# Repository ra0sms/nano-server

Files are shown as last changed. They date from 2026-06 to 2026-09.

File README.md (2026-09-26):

# Nano Server — Remote Radio Station Server

**Nano Server** is a server-side component of a remote ham radio station system. It runs on a **NanoPi NEO** single-board computer with **Armbian** and provides audio streaming, PTT control via GPIO, video streaming, relay switching, CAT interface forwarding, CW keying, and a web-based configuration interface.

Desktop client software: https://github.com/ra0sms/caesar-client-desktop

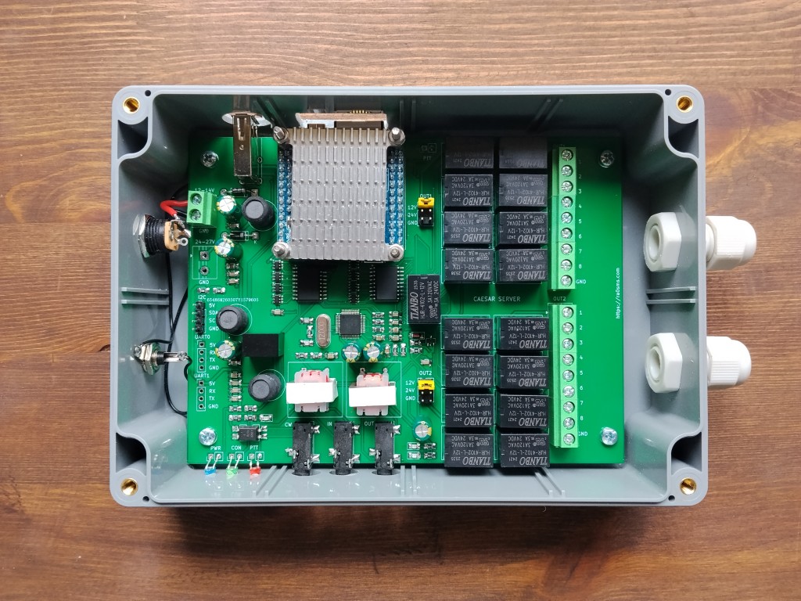
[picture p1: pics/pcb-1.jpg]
PCB


---

## Features

- 🎙️ **Bidirectional audio** over UDP (GStreamer + Opus codec)
- 📡 **PTT control** via GPIO with client reachability monitoring
- 📷 **Video streaming** via mjpg-streamer (MJPEG over HTTP)
- 🔌 **Relay control** via I2C (2×PCF8574T, 16 relays total)
- 🌐 **Web interface** — relays, TRX, band relay rules, audio, config, settings, self-update (single UI on port 5050)
- 🔗 **CAT interface** forwarding over TCP (Icom CI-V and Kenwood protocols)
- 🔄 **UART1 transparent relay** — CAT data duplicated to physical UART1 port for local computer access
- 🔒 **Fail-safe** — PTT is forced OFF when client disconnects; a CW message in progress is stopped and the CW key line released too (with break-in the radio would otherwise keep transmitting on the key alone)
- 🚫 **PTT Lock** — relay switching (manual and band relay) is blocked while PTT is active to prevent accidental antenna switching during transmission
- 🎛️ **Band Relay Rules** — automatic relay switching based on transceiver frequency
- 🔑 **CW Keyer** — Winkeyer protocol over UDP, generates Morse code on GPIO PC1
- 🔄 **Self-update** — checks GitHub for a newer release tag, shows its changelog, and applies it (`git pull` + restart of all related systemd services) from the web UI

---

## Hardware

| Component | Details |
|---|---|
| SBC | NanoPi NEO (Allwinner H3) |
| OS | Armbian (Debian Bookworm or later) |
| Audio | USB sound card (C-Media USB Audio Device) |
| Camera | USB webcam on `/dev/video1` |
| Relay board | 2× I2C GPIO expander at `0x20` / `0x21` |
| CAT interface | USB-to-Serial (port chosen in web Settings tab, e.g. `/dev/ttyUSB0`) |
| CAT UART1 relay | Physical UART1 on `/dev/ttyS1` (pins 8-TX, 10-RX) |
| CON LED | GPIO PC2 (line 66) |
| PTT output | GPIO PC3 (line 67) |
| CW Keyer output | GPIO PC1 (line 65) |

---

## Architecture

```
Client PC                          NanoPi NEO (Server)
─────────────────────────────────────────────────────────
                    UDP :5000  ←──  Audio TX (mic → client)
                    UDP :5000  ──→  Audio RX (client → speaker)
                    UDP :5001  ──→  PTT commands (0/1)
                    UDP :5002  ←→   Ping / RTT monitoring
                    UDP :5003  ──→  CW Keyer (Winkeyer protocol, UDP)
                    TCP :5050  ←──  Web UI (Flask): relays, TRX, band relay, audio, config, settings, update (live status over SSE)
                    TCP :6789  ←──  CW XML-RPC (PyWinKeyerSerial / not1mm)
                    TCP :8081  ←──  MJPEG video stream
                    TCP :3001  ←──  CAT (Icom CI-V or Kenwood)

Local PC (UART1)                   NanoPi NEO (Server)
─────────────────────────────────────────────────────────
                    UART1 (ttyS1) ←→  Transparent CAT relay (bidirectional)
```

### Systemd services

| Service | Description |
|---|---|
| `ptt_server` | PTT + CW Keyer + client monitor + ping responder (single service, all GPIO) |
| `audio_server` | GStreamer audio TX (server mic → client) |
| `audio_client_on_server` | GStreamer audio RX (client → server speaker) |
| `relay-web` | Web UI: relays, TRX, band relay, audio, config, settings, update (port 5050) |
| `mjpeg-streamer` | MJPEG video stream from USB camera |
| `alsa_restore` | Restores ALSA mixer state at boot |

---

## Installation

### 1. Flash Armbian to SD card and boot NanoPi NEO

### 2. Clone the repository

```bash
git clone https://github.com/ra0sms/nano-server.git
cd /home/pi/nano-server
```

### 3. Run the install script as root

```bash
sudo bash install_server.sh
```

The script will:
- Install all required packages (GStreamer, Flask, gpiod, mjpg-streamer, etc.)
- Build and install **mjpg-streamer** from source
- Create `client_ip.cfg`, `server_ip.cfg`, and `web/password.txt` with defaults
- Configure hardware overlays in `/boot/armbianEnv.txt`
- Register and start all systemd services
- Add sudoers entries for `restart_services_on_server.sh`, `systemctl restart/stop/start relay-web`, and `alsactl store` (so Audio tab volume changes persist across reboot)

### 4. Set IP addresses

```bash
echo '192.168.1.100' > /home/pi/nano-server/client_ip.cfg   # IP of the client PC
echo '192.168.1.10'  > /home/pi/nano-server/server_ip.cfg   # IP of this server
```

Or use the web interface at `http://<server-ip>:5050/`.

### 5. Change the default password for the web panel

```bash
echo 'yourpassword' > /home/pi/nano-server/web/password.txt
```

### 6. (Optional) Fix ALSA card order

If you have multiple USB audio devices (e.g., webcam with mic), the C-Media USB Audio card may not be card 0. Run:

```bash
sudo bash /home/pi/nano-server/fix_alsa_card_order.sh
sudo reboot
```

### 7. Reboot

```bash
sudo reboot
```

---

## Armbian Hardware Configuration

The script `setup_armbian_env.sh` patches `/boot/armbianEnv.txt` to enable the required device tree overlays. It **never modifies** `rootdev` or `rootfstype` so the system remains bootable.

To apply manually on a running system:

```bash
sudo bash /home/pi/nano-server/setup_armbian_env.sh
sudo reboot
```

Required overlays: `i2c0 uart1 uart2 uart3 usbhost0 usbhost1 usbhost2 usbhost3 w1-gpio`

---

## Web Interface — port 5050

Access at `http://<ip>:5050/` (password protected).
Default password: `1234` — change it in `web/password.txt`.

| Tab | Description |
|---|---|
| Main | Relay switching (16 relays, toggle/switch modes) and camera view |
| TRX | Transceiver frequency, band, mode display, and **Band Relay** frequency-based automatic relay switching rules |
| Audio | Speaker and mic level control via ALSA, audio stream settings (sample rate/buffer), restart audio services |
| Config | IP addresses, saved profiles, network status (client RTT / connection status, local IP) |
| Settings | Relay names, group modes, TRX serial port and protocol, UART1 transparent relay toggle |
| Update | Check GitHub for a newer release, view its changelog, apply the update and restart the web panel |

### Persistent Status Bar & Real-Time Updates

A **status bar** is shown at the top of every tab with the current PTT state, the transceiver online/frequency indicator, and the client link latency (RTT):

- **PTT** — turns red (`● PTT: ON`) while transmitting, grey otherwise.
- **TRX** — `🟢 ONLINE` / `🔴 OFFLINE` plus the live frequency.
- **Client** — round-trip time to the client PC in milliseconds.

Live values are pushed to the browser over **Server-Sent Events** (SSE, `GET /events`). The server sends a combined snapshot (PTT, relay state, TRX frequency/band/mode, client RTT, band-relay current state) that is emitted only when it changes, replacing the previous per-tab HTTP polling every 2 s. This makes status changes appear immediately and reduces load on the device. The SSE stream requires an authenticated session (cookies are sent automatically by the browser) and reconnects automatically if dropped.

### Band Relay Rules

Configure which relays activate for each frequency range (in kHz). Rules use `from ≤ freq < to` logic (lower bound inclusive, upper bound exclusive). To avoid gaps, set `to` of one rule equal to `from` of the next.

Example:
- `1800-1840` kHz → relays 1, 2
- `1840-1900` kHz → relays 3, 4
- `7000-7300` kHz → relays 5, 6

Auto-switching can be toggled on/off via a checkbox in the TRX tab. Rules are validated on the server (numeric `from < to` in kHz, relay numbers 1–16); if `web/band_rules.json` is unreadable at startup, it is renamed to `band_rules.json.invalid` and the default rules are used.

**Group-scoped auto-switching:** auto-switching only touches the relay group(s) that the configured rules actually reference, leaving the other group fully manual:

- If the saved rules only use relays **1–8**, then relays **9–16** are never reset or switched automatically — they can be selected manually and their state is preserved across every frequency change (and vice versa).
- If the rules reference relays from both groups, both are auto-managed (all selected relays are reset and re-applied as before).
- If no rule references any relay, auto-switching leaves all 16 relays untouched.

This makes it possible to dedicate one relay group to automatic antenna/band switching while keeping the other group for manually-controlled devices.

**Switching only on a band change, with confirmation:** relays are switched only when the frequency moves into a range with a *different* relay set, and only after two frequency readings at least 0.3 s apart agree. This means:

- a single corrupted CAT frame can't flip the antenna;
- tuning back and forth across a range boundary doesn't chatter the relays;
- a relay toggled by hand inside an auto-managed group stays as set until the next band change (it is no longer reset on every CAT reading).

While a band change waits for its confirming reading, the server polls the transceiver right away (subject to the external-program collision guard), so the switch still happens promptly. Saving the rules or re-enabling auto-switching re-applies them on the next reading.

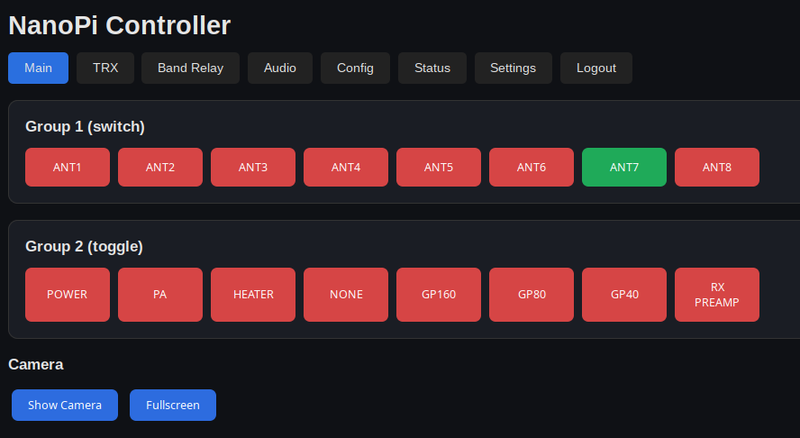
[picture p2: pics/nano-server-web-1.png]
WEB1


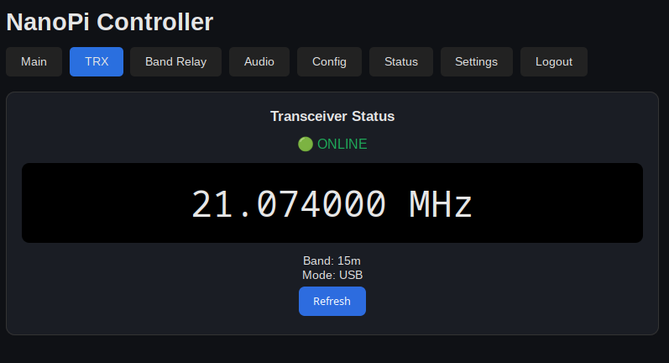
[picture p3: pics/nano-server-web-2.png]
WEB2


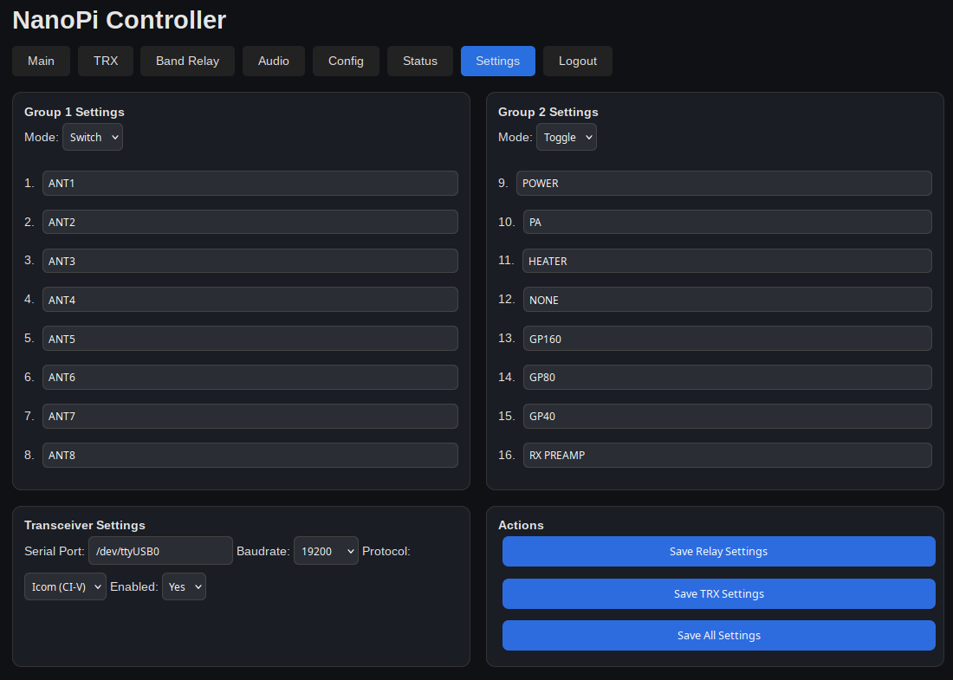
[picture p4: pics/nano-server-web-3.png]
WEB3


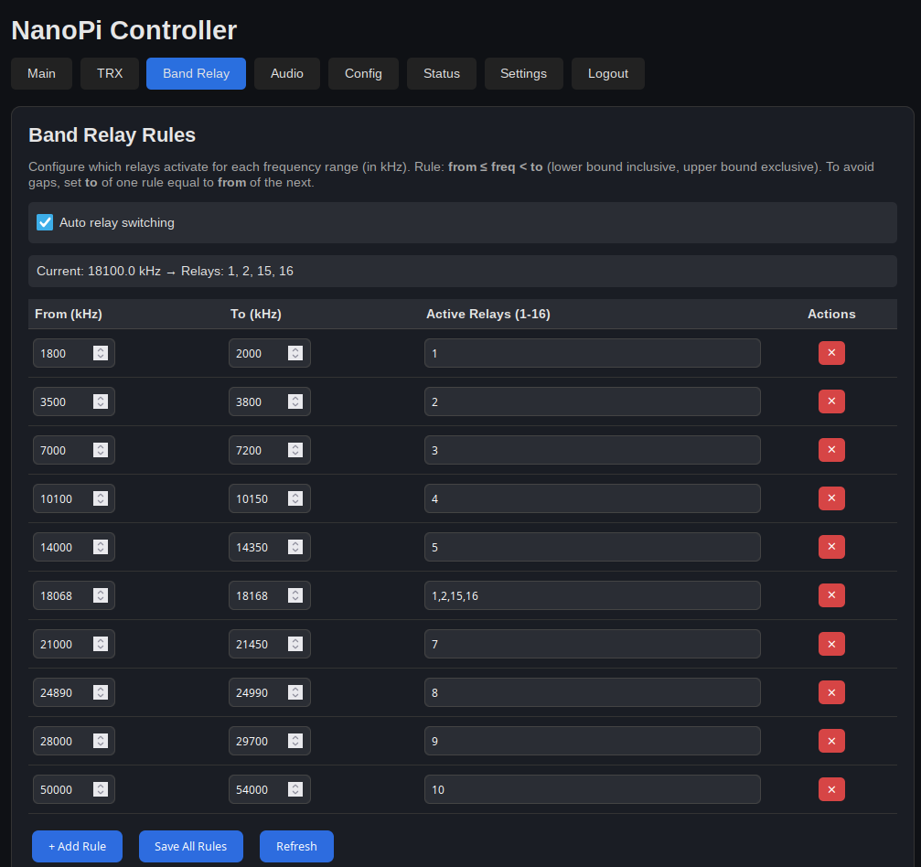
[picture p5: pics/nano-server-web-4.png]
WEB4


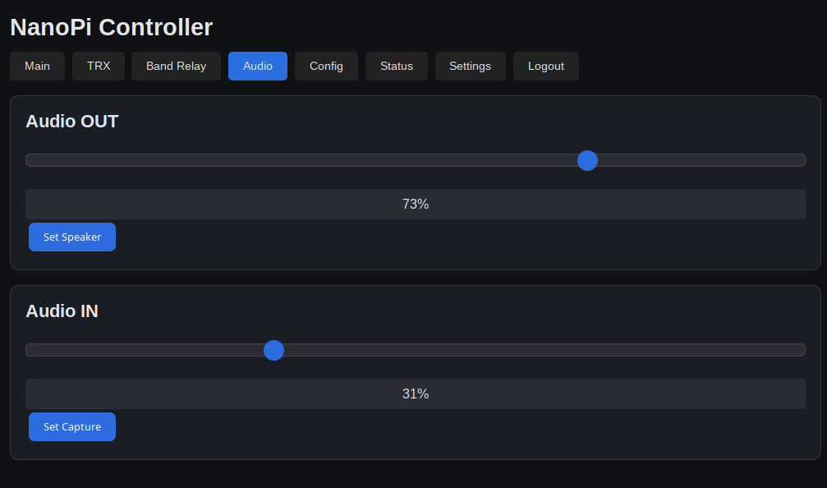
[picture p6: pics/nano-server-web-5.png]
WEB5


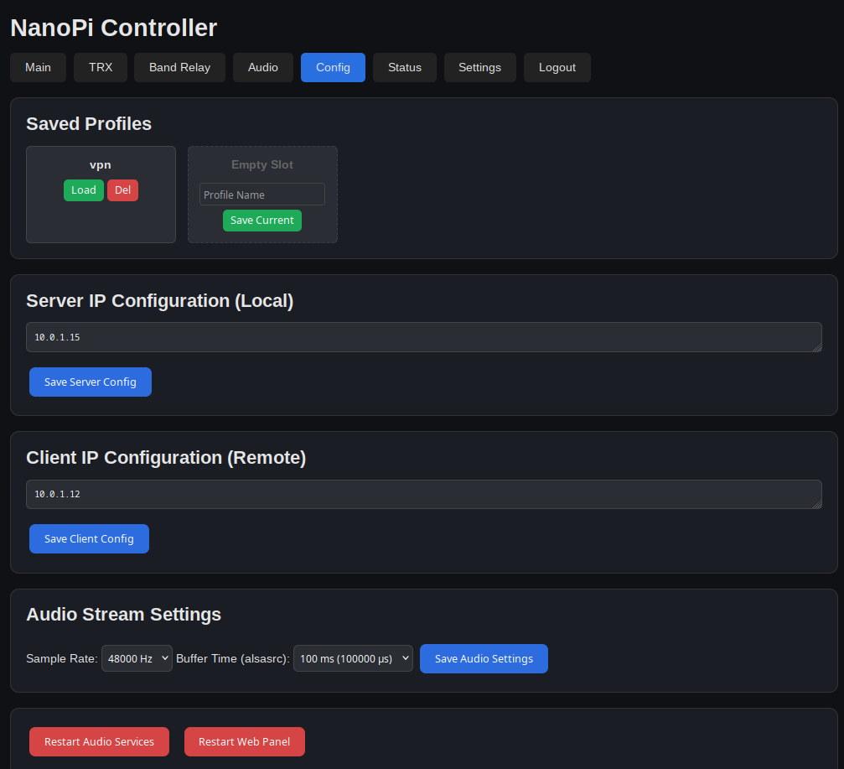
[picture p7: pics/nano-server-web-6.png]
WEB6


### PTT Lock — Relay Protection During Transmission

When PTT is active (transmitting), all relay switching is automatically blocked to prevent accidental antenna switching during transmission. This protects both the transceiver and the antenna system.

**How it works:**
1. [`combined_ptt_service.py`](network/combined_ptt_service.py) broadcasts the GPIO PTT status via UDP on `127.0.0.1:5004` on every change **and as a heartbeat every ~0.3 s**
2. [`web/app.py`](web/app.py) listens for these broadcasts in a background thread. If no status has arrived for 1.5 s (the web panel just restarted, or `ptt_server` is stopped/crashed), the PTT state is treated as **unknown and relays stay locked**
3. **CAT PTT** is tracked too, since programs like JTDX/WSJT-X/flrig often key the radio over CAT instead of the GPIO line:
   - TX/RX commands external programs send through the TCP port or UART1 relay (Kenwood `TX…;` / `RX…;`, Icom CI-V `1C 00 01` / `1C 00 00`)
   - the radio's own reports: TX/RX flag in the Kenwood `IF` reply and `TX…;`/`RX…;` auto-information, the Icom reply to `1C 00` (the server polls it on alternate poll cycles)
   - if the transceiver stops answering CAT for 5 s, the CAT TX state is cleared
4. Both manual relay toggle and automatic band relay switching are blocked while GPIO PTT is on, CAT PTT is on, or the PTT state is unknown
5. The web interface visually disables relay buttons (dimmed, `not-allowed` cursor). The status bar shows `PTT: ON`, `PTT: ON (CAT)`, or an orange `PTT: NO STATUS` when `ptt_server` isn't reporting

**Blocked operations:**
- Manual relay toggle via web UI buttons
- Automatic band relay switching when transceiver frequency changes
- Direct API calls to `POST /toggle/<n>` (server-side check)
- **Retuning from the web UI** — frequency step, band buttons and `/trx/set_freq`: band relays can't follow during TX, so a band change would leave the transmitter keyed into the previous band's antenna (the request is refused with HTTP 409 and a message in the UI). Frequency steps are also refused while the transceiver is offline, instead of stepping from a made-up frequency

---

### UART1 Transparent CAT Relay

The server can transparently relay all CAT data between the transceiver (connected via the USB-to-Serial CAT port selected in web Settings) and a local computer connected to the **UART1** physical port (`/dev/ttyS1`, pins 8-TX, 10-RX on NanoPi NEO). This allows two clients to share the same CAT connection simultaneously:

- **Remote client** — connects via TCP port 3001 over the network. Only `127.0.0.1`, the client IP from `client_ip.cfg`, and the IPs listed in `tcp_allowed_ips` in `web/trx_config.json` (edit the file, then restart `relay-web`; e.g. `"tcp_allowed_ips": ["192.168.1.50"]`) may connect; other connections are closed immediately, since this port can key and retune the transmitter
- **Local computer** — connected directly via UART1 (e.g., a PC next to the server)

**How it works:**

1. All data received from the transceiver on the CAT port is duplicated to both TCP clients and UART1
2. All data received from UART1 is written back to the CAT port (and thus forwarded to the transceiver)
3. All data received from TCP clients is written to the CAT port (existing behavior)

**Configuration** (in [`web/trx_config.json`](web/trx_config.json) or via web UI Settings tab):

```json
{
    "uart1_enabled": true,
    "uart1_port": "/dev/ttyS1"
}
```

The UART1 baudrate is automatically set to match the CAT port baudrate.

**Replies to the server's own requests are not forwarded.** The server's own polls (and the web UI's TRX commands) would otherwise produce replies that external programs take as answers to their own requests, causing "unexpected reply" errors and retries in Hamlib/JTDX/flrig:

- **Icom CI-V:** the server talks to the radio from its own controller address, **Server CI-V Address** in Settings (`server_addr`, default `0xE1`), not the `0xE0` that flrig/JTDX/Hamlib use (`ctrl_addr`). The radio replies to the sender's address, so frames to or from `server_addr` (including the echo on a single-wire CI-V bus) are decoded for the web UI but not passed to TCP clients or UART1. If some radio only works with `0xE0`, set Server CI-V Address to `0xE0`: everything is then forwarded, as in older versions.
- **Kenwood:** there are no addresses, so after each `IF;` poll the next `IF…;` reply (within 0.5 s) is kept back from external programs. If UART1 is unavailable (e.g., overlay not enabled), the server logs a warning and continues without it.

**Web UI toggle:** The **Settings → Transceiver Settings** tab now includes a **"UART1 transparent relay"** checkbox. It can be turned on/off directly from the web interface and takes effect immediately (the relay is re-initialized without restarting the service).

**Poller behavior with the relay enabled:**

When the UART1 transparent relay is enabled, the CAT bus can be owned by an external program on the PC (e.g. **flrig**, **TR4W**, **Hamlib**). While the external program is **actively** exchanging data, the server's internal poller backs off so its queries do not interleave with the PC's requests on the same line and corrupt the response stream.

However, the server now **automatically resumes its own polling whenever the external program is silent or absent**:

- **Relay ON + external program active** → the server's poller stays quiet; the PC program reads the transceiver directly, and the web **TRX tab** stays updated passively by decoding the responses that flow through the bridge.
- **Relay ON + external program silent/absent** → the server only skips its own poll while an external controller (via UART1 or a TCP client) has sent something within the last 0.3 s, or while the radio has answered within the last 2 s (someone is already keeping the frequency fresh). Otherwise it polls the transceiver itself, so the web **TRX tab** still shows the live frequency/mode even when no PC program is running. As soon as the external program sends traffic again, the poller hands the port back within one poll cycle.
- **Relay OFF** → internal poller enabled; the web interface queries the transceiver itself and updates the TRX tab even when no PC program is connected.

This behavior applies to **both** CAT protocols (Icom CI-V and Kenwood).

"Recently" means the radio has reported the **active** frequency in the last 2 s; other CAT traffic doesn't count (e.g. Hamlib reading only the inactive VFO).

**What the web panel decodes:**

- **Icom CI-V:** frequency and mode replies (`03`/`04`) and the radio's own **transceive** reports (`00`/`01`). With *CI-V Transceive* enabled in the radio's menu, frequency changes arrive as soon as the dial moves, so band relays react without waiting for a poll. Modes: LSB, USB, AM, CW, CW-R, RTTY, RTTY-R, FM, WFM, DV, DD. 6-byte frequencies (10 GHz+ bands, IC-905) are supported.
- **Kenwood:** `IF` (frequency, mode, TX/RX and **active VFO**), `FA`/`FB`, `MD`, `FR`. `FA`/`FB` only update the displayed frequency and band relays when they are for the VFO the radio is operating on (learned from `IF`, `FR` reports and `FR` commands external programs send). Otherwise, working on VFO B would switch antennas by VFO A's frequency. Frequency changes from the web UI are sent to the active VFO (`FB` when on VFO B).

**Stability & auto-recovery:**

All writes to the CAT port are serialized through a single thread lock (`ser_lock`), and data from each external source (every TCP client and UART1) is first split into **whole CAT frames** (terminated by `;` for Kenwood, `0xFD` for CI-V) — only complete frames are written. So a command that arrives in pieces (e.g. `F` in one TCP segment and `A;` in the next) can never have the poller's or another client's frame inserted into its middle. An unterminated tail is passed through as-is after 0.5 s. The CAT port and UART1 are read without a fixed 100 ms wait, so replies reach JTDX/flrig and UART1 immediately. Additionally, if the CAT serial port raises a read error (e.g. a temporary USB hiccup or the transceiver is powered off), the server now **automatically closes and reopens the serial ports** with retries instead of silently stalling — so a remote `JTDX`, `flrig`, or `WSJT-X` session no longer needs a full service restart to recover. Manually re-initializing from the web UI (Reconnect button / `POST /trx/reinit`) and re-initializing after a config change are also guarded by the same lock.

**Prerequisite:** UART1 overlay must be enabled in `/boot/armbianEnv.txt`:
```
overlays=i2c0 uart1 uart2 uart3 usbhost0 usbhost1 usbhost2 usbhost3 w1-gpio
```

---

## Profiles

Up to 5 configuration profiles (server IP, client IP, audio settings) can be saved and loaded from the web configuration interface. Profile files are stored in `profiles/`.

---

## Restarting Services

To restart all runtime services at once:

```bash
sudo /home/pi/nano-server/restart_services_on_server.sh
```

Or restart individual services:

```bash
sudo systemctl restart ptt_server.service
sudo systemctl restart audio_server.service
```

To restart the web panel from the UI, use the **"Restart Web Panel"** button on the Update tab (requires sudoers NOPASSWD for `systemctl restart relay-web`). The **"Restart Audio Services"** button on the Audio tab restarts `audio_server`, `audio_client_on_server`, `mjpeg-streamer`, and `ptt_server` (via `restart_services_on_server.sh`).

To reload `client_ip.cfg` without restarting the PTT service:

```bash
sudo systemctl kill -s SIGHUP ptt_server.service
```

---

## Software Update

The **Update** tab checks GitHub for a newer release and applies it without needing SSH access to the server.

- **Check for Update** fetches tags from `origin` and compares the highest `vX.Y.Z` tag to the version reachable from the currently checked-out commit (`git describe --tags`). If a newer one exists, it shows every `CHANGELOG.txt` section newer than the current version (not just the latest one), read directly from the fetched tag so it's visible even before pulling.
- **Update** runs `git pull --ff-only`, then restarts `audio_server`, `audio_client_on_server`, `mjpeg-streamer`, and `ptt_server` (via `restart_services_on_server.sh`), and finally restarts `relay-web` itself.
- Before pulling, it refuses if the checkout has local changes to any **tracked** file, or **any untracked file at all**, outside of the app's own runtime-state files (`web/config.json`, `audio/audio_config.cfg`, `web/trx_config.json`, `web/band_rules.json` — these are gitignored and rewritten by the app itself, so their local content is preserved across the pull automatically). A stray file left in the checkout (e.g. a manual backup) will block the update until it's removed or committed elsewhere.

Cutting a new release: add a `## vX.Y.Z (date)` section with a bullet list to the top of `CHANGELOG.txt`, commit, then tag and push:

```bash
git tag vX.Y.Z
git push origin main
git push origin vX.Y.Z
```

---

## Audio Configuration

Edit `audio/audio_config.cfg`:

```ini
RATE=48000       # sample rate: 48000 or 24000 Hz
LATENCY=100000   # buffer time in microseconds (100 ms)
```

Or use the **Audio Stream Settings** section on the **Audio** page in the web UI.

The web panel auto-detects the ALSA card (looks for C-Media USB Audio in `/proc/asound/cards`) and the speaker control name. Mic capture is hardcoded to `numid=8` (`Mic Capture Volume`).

---

## CW Keyer (Winkeyer Protocol)

The CW Keyer is integrated into the **`ptt_server`** service (single process, single GPIO request). It implements the **K1EL Winkeyer protocol** over UDP, generating Morse code (CW) on **GPIO PC1** (line 65).

All GPIO lines (CW=PC1, CON=PC2, PTT=PC3) are requested in a single `gpiod.request_lines()` call to avoid conflicts between separate processes on the same gpiochip.

### How it works

1. The client sends Winkeyer protocol commands via UDP to port **5003**
2. The server buffers ASCII characters and sends them as CW on GPIO PC1
3. The output pin (PC1) drives a transistor/keying circuit connected to the transceiver

### Supported commands

| Byte | Command | Description |
|---|---|---|
| `0x00` + WPM | Set speed | WPM value (5-99) |
| `0x02` | Start sending | Begin transmitting buffer |
| `0x03` | Clear buffer | Reset and stop |
| `0x0A` (LF) | Start sending | Same as 0x02 |
| `0x1B` | Immediate stop | Abort transmission |
| `0x1F` | Request status | Reply: 0x00 (idle) or 0x01 (busy) |
| `0x20`-`0x7E` | ASCII chars | Add to send buffer |
| `0x7F` | Backspace | Remove last char from buffer |

### Usage

```bash
# Send "CQ CQ DE RA0SMS" at 25 WPM
echo -ne '\x00\x19CQ CQ DE RA0SMS\x0a' | nc -u <server-ip> 5003
```

### XML-RPC interface (PyWinKeyerSerial / not1mm compatible)

The service provides an **XML-RPC server on TCP port 6789**, compatible with the [K6GTE PyWinKeyerSerial](https://github.com/mbridak/PyWinKeyerSerial) interface. This allows logging programs like **[not1mm](https://github.com/mbridak/not1mm)** to send CW directly to the server.

**Port 6789 is the CW connection used by not1mm.** In not1mm's CW settings this corresponds to `cwport = 6789` with `cwtype = 2` (`PyWinKeyerSerial`). The corresponding not1mm UI fields are:
- **Settings → CW Interface → Type**: `PyWinKeyerSerial`
- **Settings → CW Interface → IP**: `<server-ip>`
- **Settings → CW Interface → Port**: `6789`

> ⚠️ **Important — re-check not1mm.json manually after any IP change.** not1mm stores its CW server address in the **`cwip`** field of its settings file **`~/.config/not1mm/not1mm.json`**. If the IP address of this Nano Server changes, you must edit `cwip` in that file (and ideally restart not1mm), because **not1mm will not start / will fail to work if the configured `cwip` is unreachable**. The `cwport` (must be `6789`) and `cwtype` (must be `2`) are stored there as well.

Example `~/.config/not1mm/not1mm.json` (relevant CW fields):

```json
{
    "cwip": "10.0.1.16",
    "cwport": 6789,
    "cwtype": 2,
    "useflrig": true,
    "cw_speed": 30
}
```

Available RPC methods:

| Method | Description |
|---|---|
| `k1elsendstring(text)` | Send a string to the CW buffer and start transmitting |
| `setspeed(wpm)` | Set CW speed (5-99 WPM) |
| `sendblended(text)` | Send a prosign/blended message |
| `tuneon()` | Key down and hold (tune mode) |
| `tuneoff()` | Stop key down |
| `clearbuffer()` | Clear the CW buffer and stop sending |

Example using Python:

```python
import xmlrpc.client
proxy = xmlrpc.client.ServerProxy("http://<server-ip>:6789/RPC2")
proxy.k1elsendstring("CQ CQ DE RA0SMS")
proxy.setspeed(25)
```

### Service management

```bash
sudo systemctl status ptt_server.service
sudo systemctl restart ptt_server.service
sudo journalctl -u ptt_server.service -f
```

---

## Project Structure

```
nano-server/
├── install_server.sh              # Main installation script
├── setup_armbian_env.sh           # Patches /boot/armbianEnv.txt safely
├── restart_services_on_server.sh  # Restart all runtime services
├── fix_alsa_card_order.sh         # Fix USB audio card order via modprobe
├── setup_sudo_nopasswd.sh         # Configure sudoers for web panel self-restart
├── create_ser2net_yaml.sh         # Generate ser2net config
├── client_ip.cfg                  # Client IP (git-ignored)
├── server_ip.cfg                  # Server IP (git-ignored)
├── CHANGELOG.txt                  # Per-version release notes, read by the Update tab
├── armbianEnv.txt                 # Reference overlay config
├── audio/
│   ├── audio_server.sh            # GStreamer TX pipeline
│   ├── audio_client_on_server.sh  # GStreamer RX pipeline
│   └── audio_config.cfg           # Rate and buffer settings (git-ignored, written by the app)
├── network/
│   └── combined_ptt_service.py    # PTT + CW Keyer + client monitor + ping responder
├── web/
│   ├── app.py                     # Web UI: relays, TRX, band relay, audio, config, settings, update (+ live status via SSE /events)
│   ├── templates/index.html       # Web UI page markup (rendered via render_template)
│   ├── static/css/style.css       # Web UI stylesheet
│   ├── static/js/main.js          # Web UI client-side logic
│   ├── config.json                # Relay names and group modes (git-ignored, written by the app)
│   ├── trx_config.json            # TRX serial port and protocol settings (git-ignored, written by the app)
│   ├── band_rules.json            # Band relay frequency rules (git-ignored, written by the app)
│   └── password.txt               # Web UI password (git-ignored)
├── systemd/                       # Service unit files
├── profiles/                      # Saved configuration profiles (git-ignored)
└── docs/
    ├── gpio-info.txt              # GPIO line numbers reference
    └── nano-pinout.jpg            # NanoPi NEO pinout diagram
└── KiCad/                         # KiCad schematic and PCB files   
```

---

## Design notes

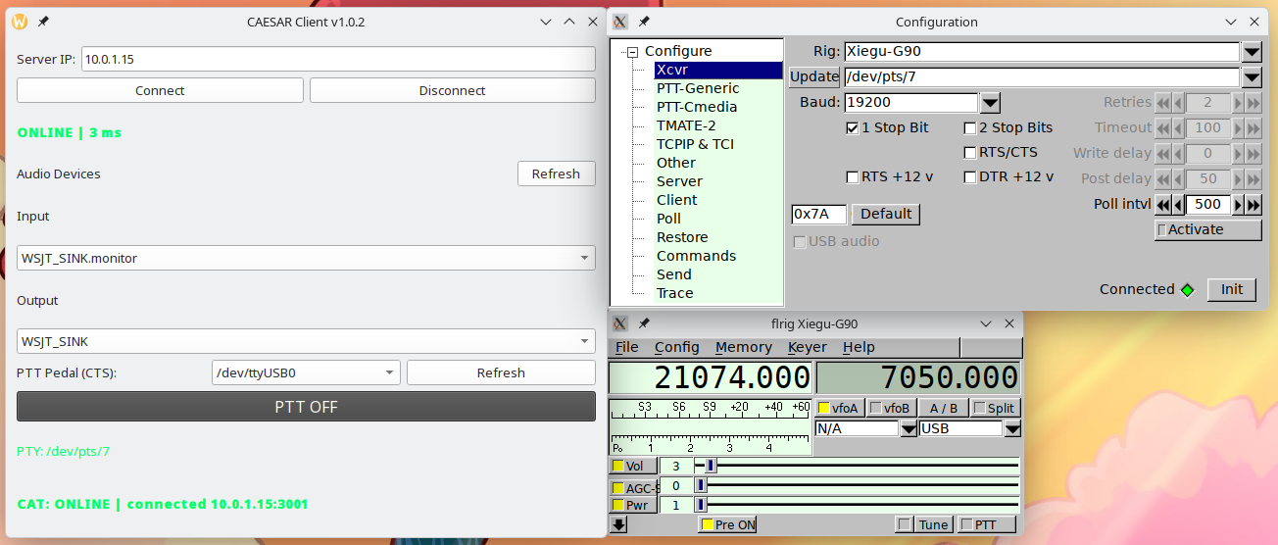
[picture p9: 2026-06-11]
pics/desktop-client-with-flrig.png

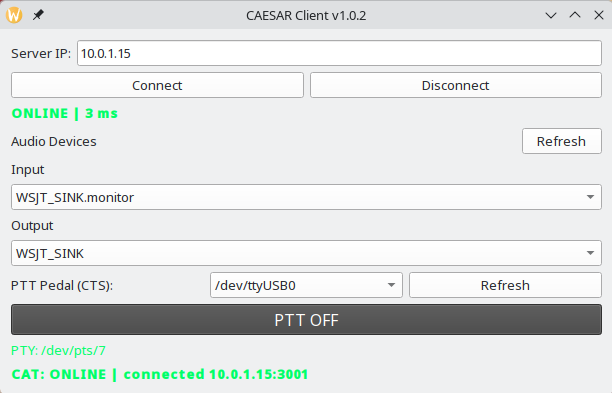
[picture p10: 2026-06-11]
pics/desktop-client-example.png

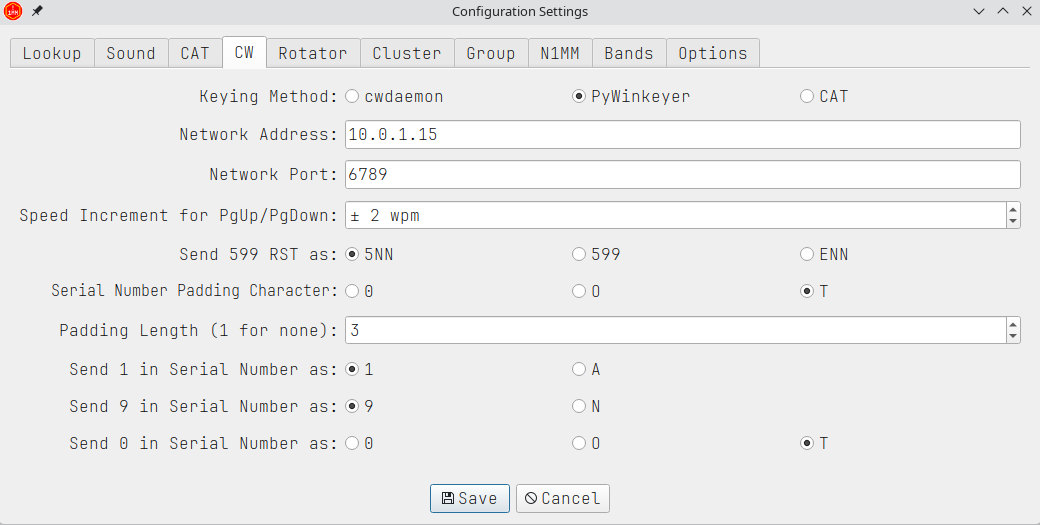
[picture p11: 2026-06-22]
pics/nano-server-winkeyer.png

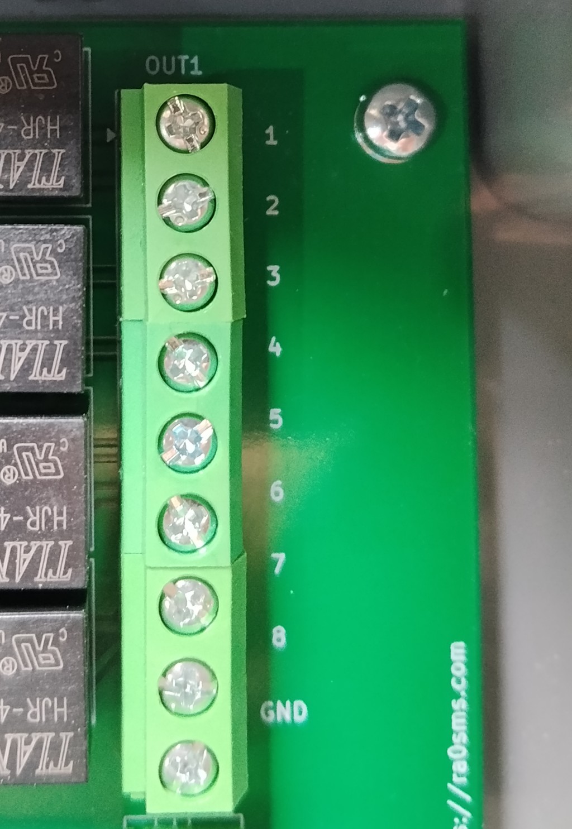
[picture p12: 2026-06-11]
pics/out-1.jpg

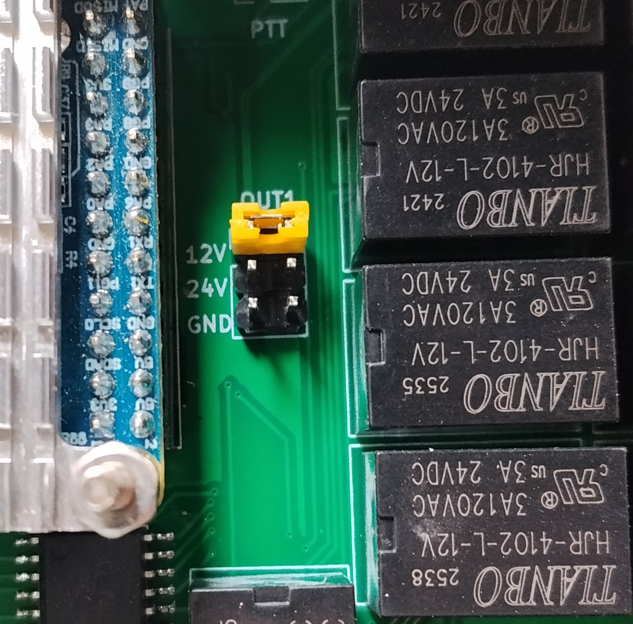
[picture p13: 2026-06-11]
pics/jamper-1.jpg

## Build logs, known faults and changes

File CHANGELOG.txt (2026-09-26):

## v1.2.3 (2026-09-26)
- Frequency changes from the web UI (step, band buttons, /trx/set_freq) are refused while PTT is active or its state is unknown: band relays can't follow during TX, so the radio would transmit into the previous band's antenna. Frequency steps are also refused while the transceiver is offline instead of jumping to 7.1 MHz
- When the client disappears, ptt_server now also stops a running CW message, clears the CW buffer and releases the key line (with break-in the radio would otherwise keep transmitting); a stopped CW message no longer finishes the current character and re-keys the transmitter
- Band relay rules are validated on the server (numeric from < to in kHz, relays 1-16); an invalid band_rules.json is kept as band_rules.json.invalid instead of being overwritten
- A CAT decoding error no longer makes the CAT port reopen on every frame: frames are still forwarded to external programs and the error is logged
- PTT/client status listeners recover from errors instead of exiting (which left every relay locked until the web panel was restarted)
- Icom CI-V: transceive reports (00/01) are decoded, so band relays follow the dial immediately with "CI-V Transceive" on; added CW-R, RTTY-R, WFM, DV, DD modes and 6-byte (10 GHz+) frequencies; longer or split FE preambles no longer lose a frame
- Kenwood: the active VFO is tracked (IF, FR), FA/FB only update the frequency and band relays for the VFO in use, and web frequency changes go to the active VFO; MD7/MD9 shown as CW-R/RTTY-R
- The server polls whenever the active frequency hasn't been reported for 2 s, even if the radio is busy answering other queries
- Removed the "Extra CAT TCP clients" field from Settings; extra IPs for CAT port 3001 can still be set in `tcp_allowed_ips` in web/trx_config.json

## v1.2.2 (2026-09-26)
- CAT: data from each external source (every TCP client and UART1) is split into whole frames before it's written to the radio, so the poller's or another client's command can no longer land in the middle of a command that arrived in pieces; the CAT port and UART1 are read without a fixed 100 ms wait, so replies reach JTDX/flrig immediately
- CAT: replies to the server's own requests are no longer forwarded to external programs — Icom CI-V: the server uses its own controller address (Settings → Server CI-V Address, default 0xE1) and frames to/from it are kept back; Kenwood: the reply to the server's own IF; poll is kept back
- CAT: the server's internal poller now runs when the external program is silent, so the TRX tab stays live with the UART1 relay enabled and no PC program running; for Icom it also polls mode and TX/RX state
- CAT PTT is detected (TX/RX commands from JTDX/WSJT-X/flrig and the radio's own TX/RX reports) and locks relay switching just like GPIO PTT
- ptt_server re-sends the PTT state every 0.3 s; relays stay locked while the web panel has no fresh PTT status (status bar shows "PTT: NO STATUS")
- Band relay switches only when the frequency enters a range with a different relay set and two readings 0.3 s apart agree: no switching on a corrupted frame, no chatter at range boundaries, and relays toggled by hand in an auto-managed group are no longer reset on every CAT reading
- Fix Icom CI-V RF power (now 14 0A + 2-byte BCD) and AF gain (14 01 + 2-byte BCD) commands
- Fix a powered-off Icom radio showing ONLINE on single-wire CI-V: echoed frames are ignored, only frames sent by the transceiver count
- Security: CAT TCP port 3001 only accepts 127.0.0.1, the client IP and IPs listed in Settings → Extra CAT TCP clients; relay toggle and band-relay apply are POST-only; session cookie is SameSite=Lax; /ptt/status and /trx/ports require login
- Client presence (CON LED, web RTT) is based on the client app's own traffic and heartbeat, not on whether the client machine answers pings, so pressing Disconnect in the client is reflected immediately
- CW keyer: deadline-based compensated timing, so dits, dahs and gaps no longer stretch from sleep overshoot
- ptt_server works with both libgpiod v1 and v2 Python bindings
- Removed the leftover ser2net restart from ptt_server
- Updated PCB layout and gerbers

## v1.2.1 (2026-09-09)
- Group-scoped automatic relay switching: if the band rules only use relays 1-8 (or only 9-16), the other group is left untouched, so those relays can still be selected manually and their state survives every frequency change
- Live web UI updates via Server-Sent Events (`/events`) replace the per-tab 2 s HTTP polling; a persistent status bar (PTT / TRX / client RTT) is now shown on every tab
- Removed the fixed `/dev/ttyCAT` binding: the CAT serial port is chosen on the web Settings tab, and `fix_usb_ports.sh` is no longer used
- Web panel no longer crashes when the I2C relay module is absent: the I2C bus and both expander addresses are probed safely at startup and every relay write is guarded
- Fix TRX showing ONLINE when no transceiver is attached: `online` now reflects an actual CAT response (with a 5 s inactivity timeout) instead of merely an opened serial port

## v1.2.0 (2026-09-07)
   - Split the web panel UI out of app.py: HTML -> web/templates/index.html, CSS -> web/static/css/style.css, JS -> web/static/js/main.js, loads static assets via url_for instead of a huge inline template)

## v1.1.10 (2026-08-30)
- No code changes — version bump to verify the Update tab's check/apply flow end-to-end

## v1.1.9 (2026-08-30)
- Fix Check for Update showing no changelog for an available update: it read CHANGELOG.txt from the working tree, which still reflects whatever commit is currently checked out, not the fetched-but-not-yet-pulled latest tag. Now reads the file from the latest tag's own git object instead

## v1.1.8 (2026-08-30)
- No code changes — version bump to verify the Update tab's check/apply flow end-to-end

## v1.1.7 (2026-08-30)
- Ignore privatekey/publickey (ser2net/TLS credentials) again so they stop showing up as local changes, without reintroducing the untracked-file check from v1.1.3 that broke Update on a deployed device

## v1.1.6 (2026-08-30)
- No code changes — version bump to verify the Update tab's check/apply flow end-to-end after the v1.1.5 fix

## v1.1.5 (2026-08-30)
- Fix the actual cause of the broken web panel (a bug present since v1.1.2, not v1.1.3 as first suspected): the changelog-rendering JS had literal "\n" sequences written inside app.py's non-raw triple-quoted HTML_TEMPLATE string, so Python's own string parsing turned them into real newline characters before they ever reached the browser, corrupting a JS comment and splitting a string literal across lines ("Uncaught SyntaxError: string literal contains an unescaped line break"), which broke every tab and button on the page. All such sequences are now properly double-escaped

## v1.1.4 (2026-08-30)
- Revert v1.1.3 (untracked-file update check + privatekey/publickey gitignore): it broke the web panel for at least one deployed device after a git pull. Back to the known-working v1.1.2 code while the cause is investigated (turned out the real bug predated v1.1.3 — see v1.1.5)

## v1.1.2 (2026-08-30)
- Update tab now shows the current version immediately on open (via a new local-only /update/current check, no GitHub call), instead of only after clicking Check for Update
- Render the changelog for an available update as formatted headings and bullet lists per version instead of a raw text block

## v1.1.1 (2026-08-30)
- Fix Update tab always refusing to apply an update ("Repository has local changes") because the app's own runtime state files (web/config.json, audio/audio_config.cfg, web/trx_config.json, web/band_rules.json) were tracked or untracked-but-not-ignored, so git always saw them as locally modified. They're now gitignored, and the update flow preserves their live content across a git pull

## v1.1.0 (2026-08-30)
- Consolidate the web panel from 8 tabs to 6: Band Relay rules moved into the TRX tab, Audio Stream Settings and the Restart Audio Services button moved into the Audio tab, the Status tab merged into Config as a "Network Status" section, and the Restart Web Panel button moved into the Update tab

## v1.0.0 (2026-08-30)
- Add Update tab to the web panel: checks GitHub for a newer release tag, shows the changelog for it, and applies the update (git pull + restart of all related systemd services) with one click
- Fix Audio tab volume settings not persisting across reboot (alsactl store lacked permission when the panel runs as the "pi" user)

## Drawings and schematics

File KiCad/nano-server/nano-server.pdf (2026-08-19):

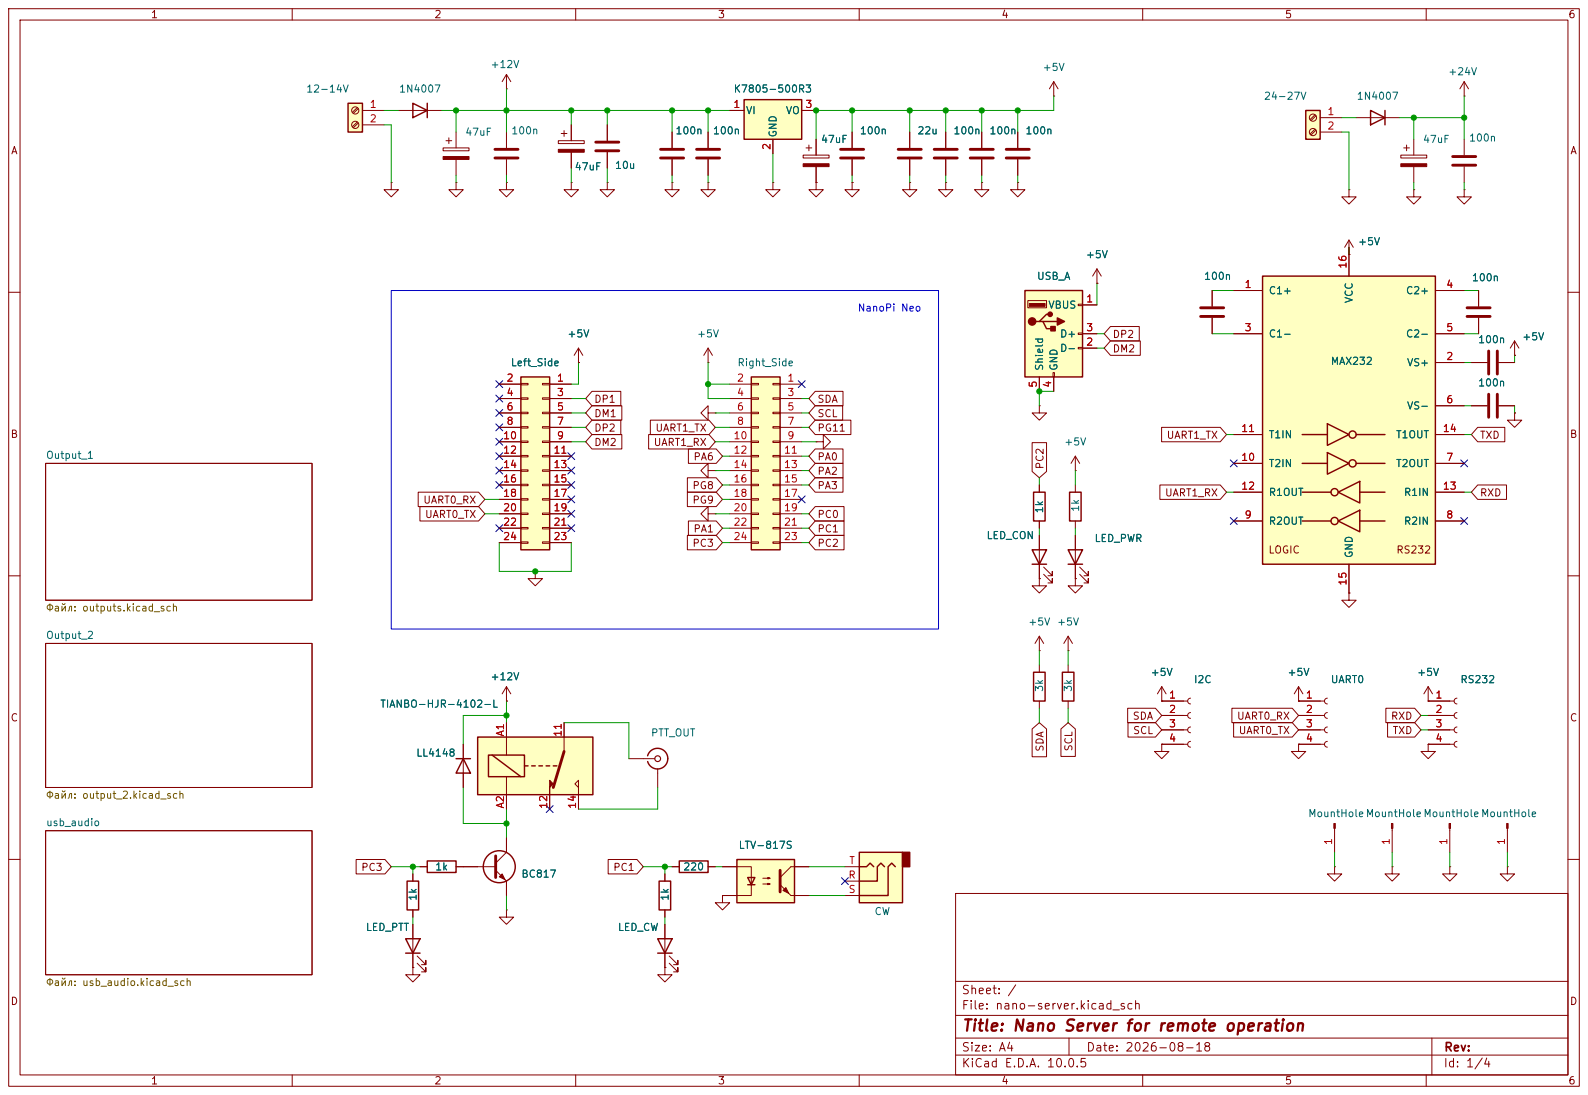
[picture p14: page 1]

1 MountHole 1 MountHole 1 MountHole 1 MountHole +12V 1

Sheet: /
File: nano-server.kicad_sch
Title: Nano Server for remote operation

Size: A4 | Rev:
KiCad E.D.A. 10.0.5 | Id: 1/4

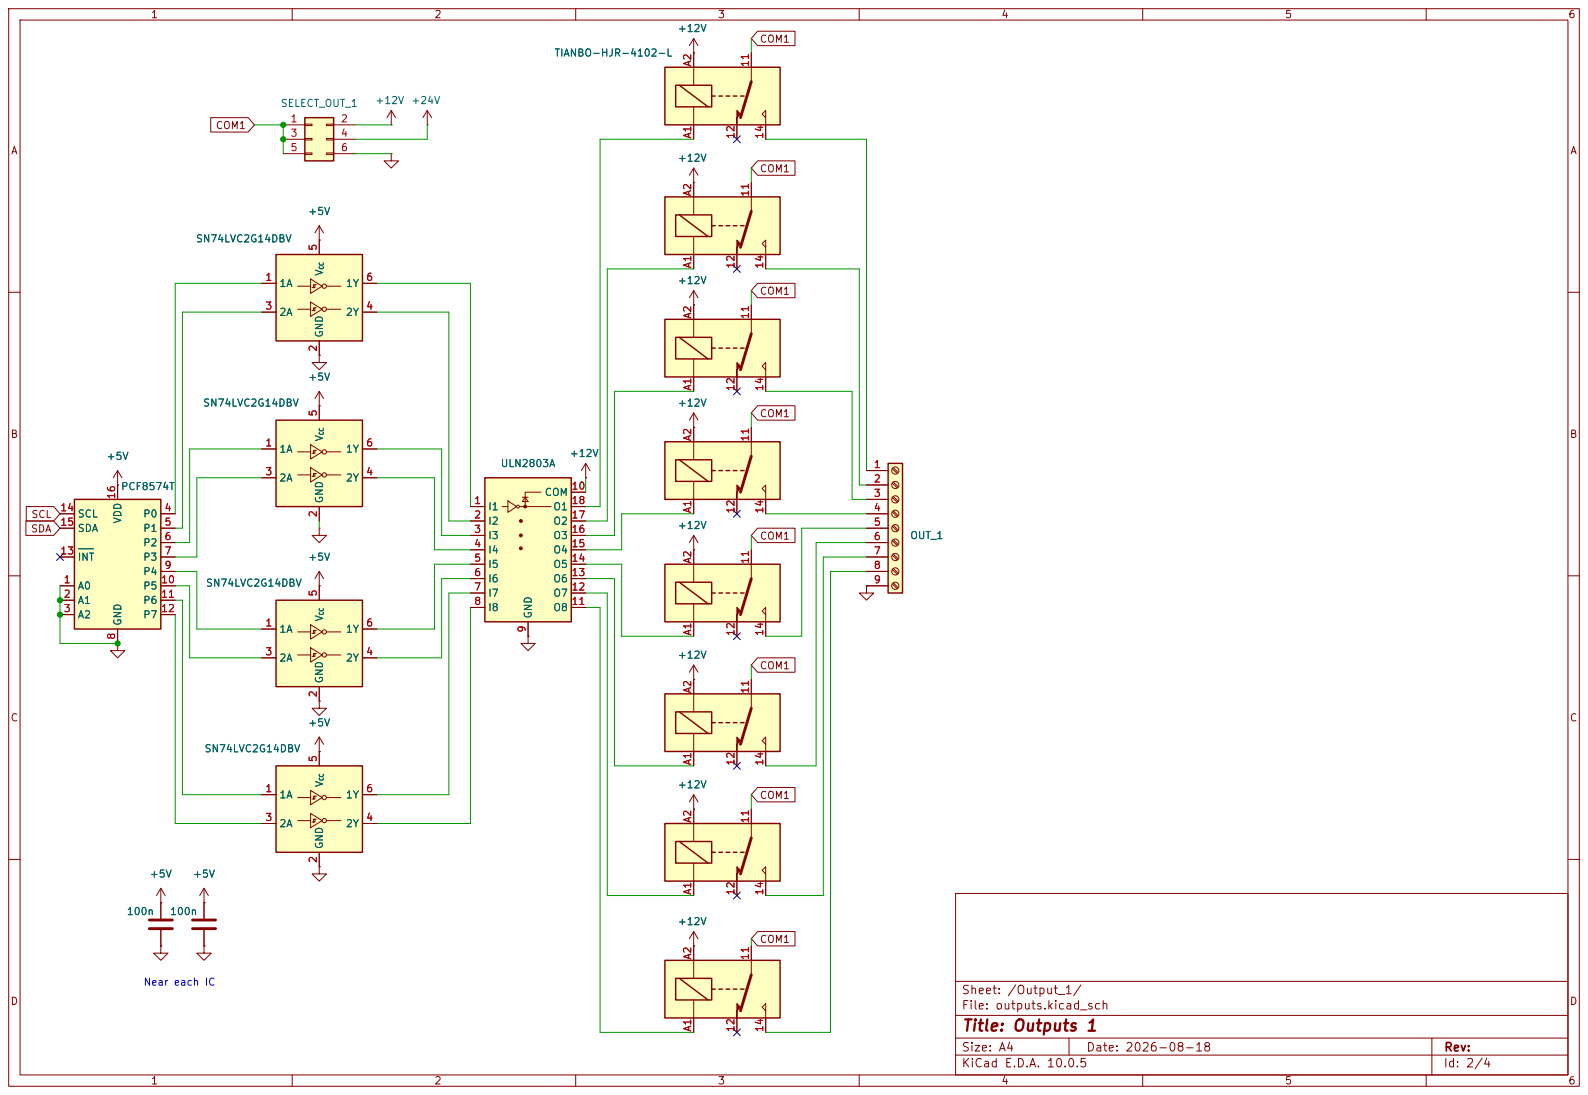
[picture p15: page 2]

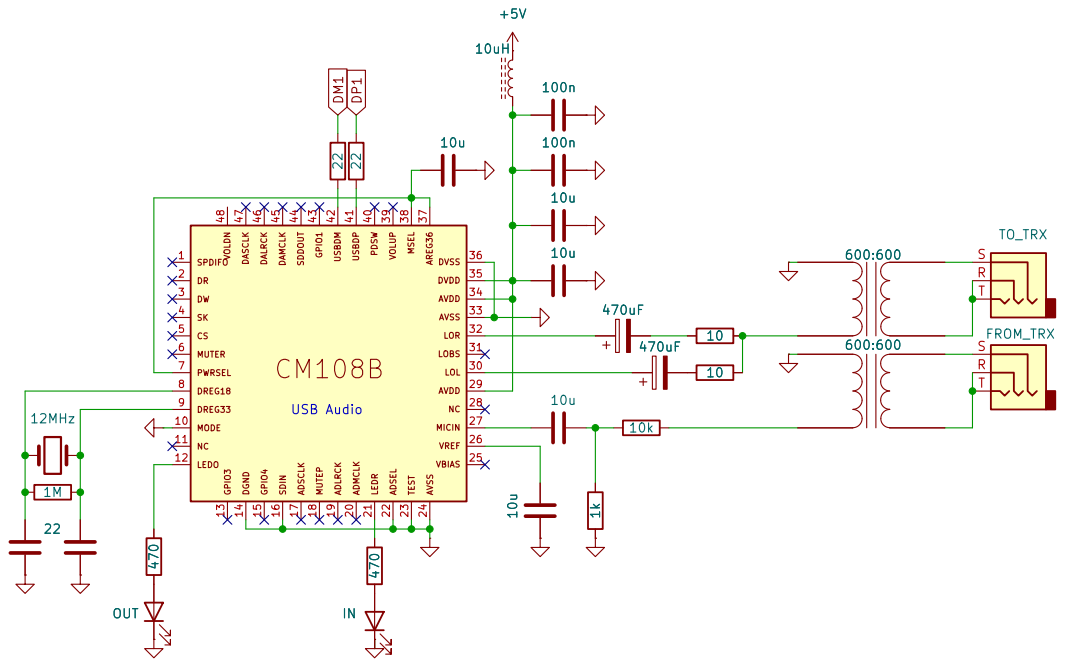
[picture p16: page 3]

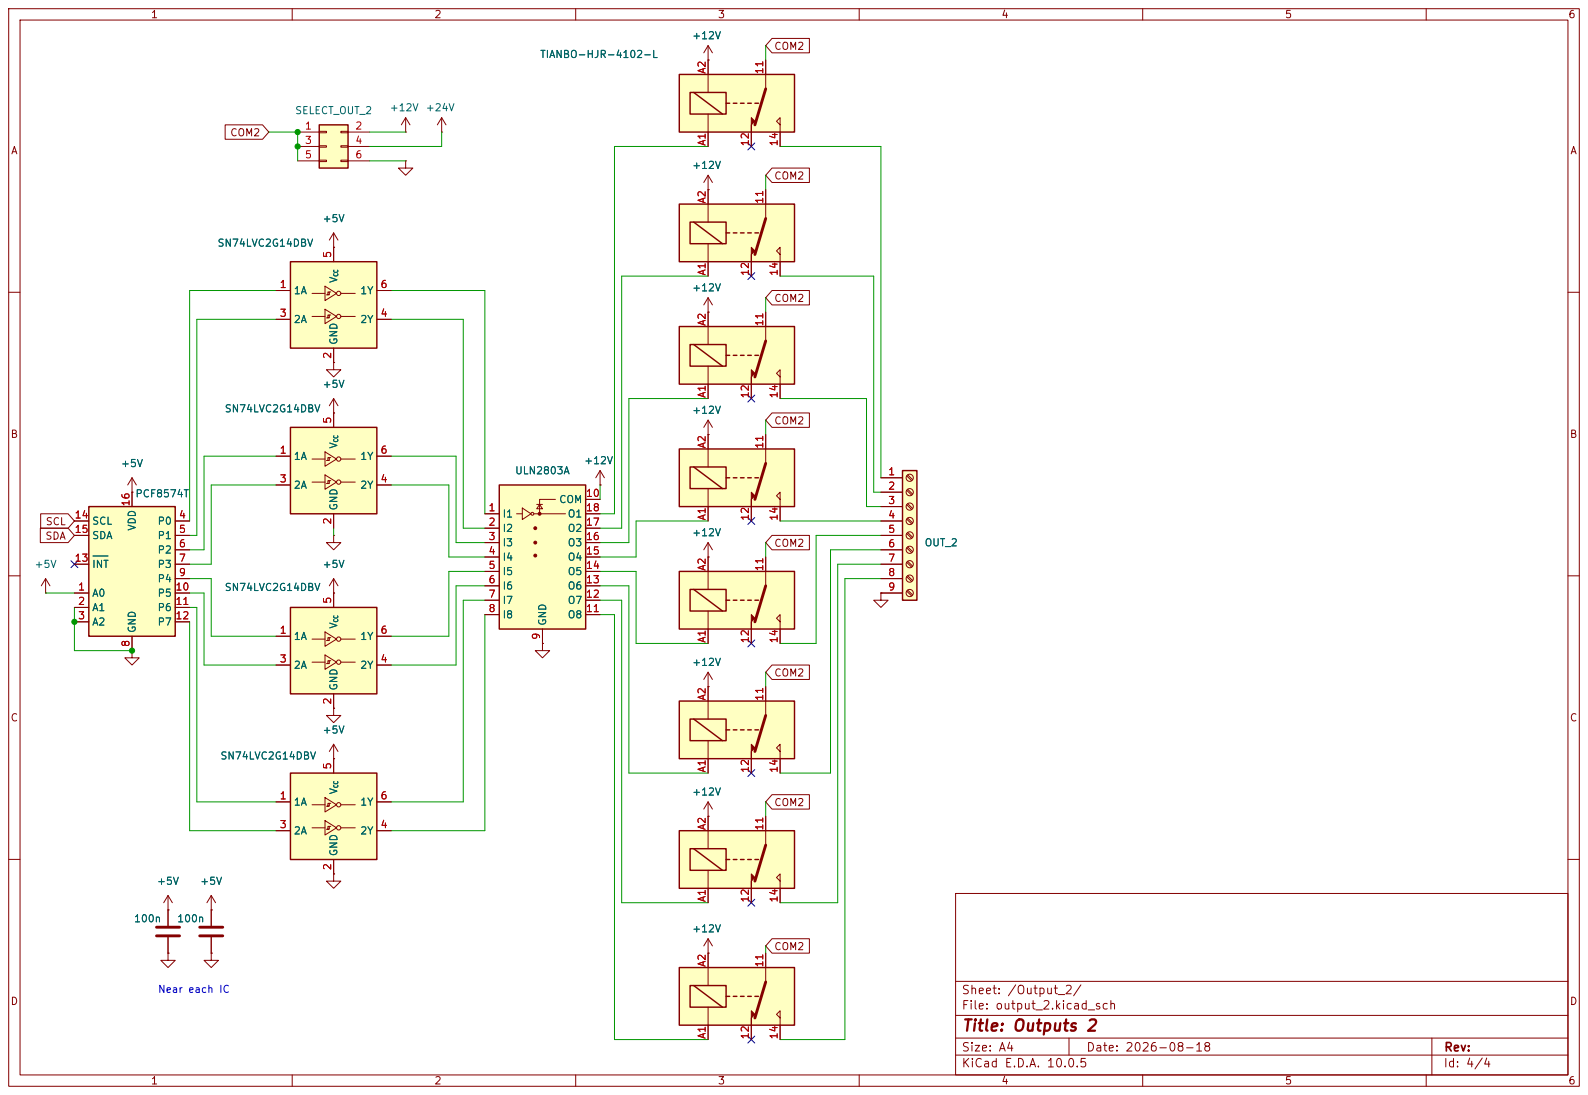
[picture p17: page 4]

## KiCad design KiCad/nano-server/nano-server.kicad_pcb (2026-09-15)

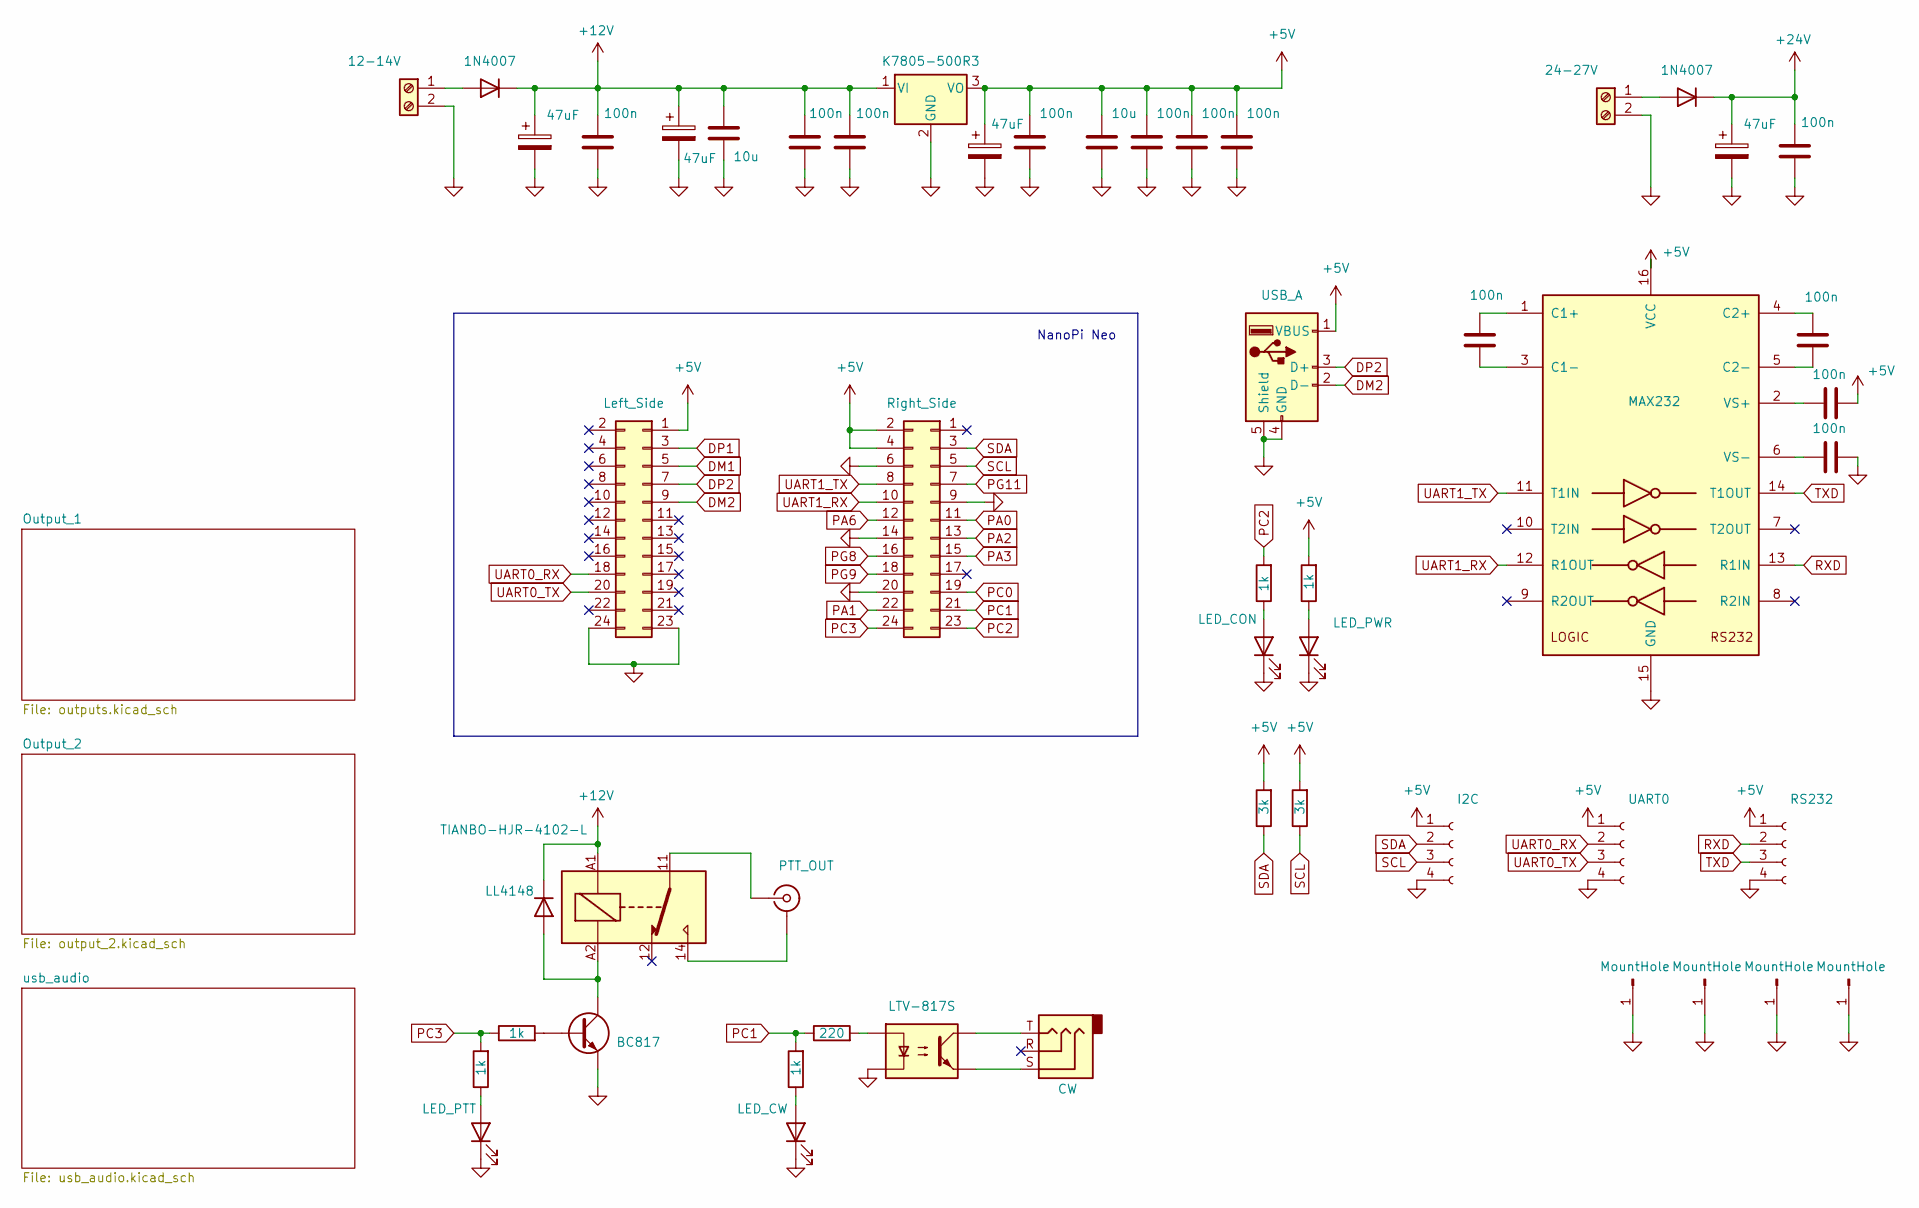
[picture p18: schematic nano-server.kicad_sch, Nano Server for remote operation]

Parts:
C1, C3, C7, C29: 47uF; CP_Radial_D5.0mm_P2.50mm
C2, C5, C6, C8, C10, C11, C12, C15, C16, C17, C30, C33: 100n; C_1206_3216Metric
C4, C9: 10u; C_1206_3216Metric_Pad1.33x1.80mm_HandSolder
D1, D8: 1N4007; D_DO-41_SOD81_P10.16mm_Horizontal
D2: LED_CON; PinHeader_1x02_P2.54mm_Vertical
D3: LED_PWR; PinHeader_1x02_P2.54mm_Vertical
D4: LED_PTT; PinHeader_1x02_P2.54mm_Vertical
D5: LL4148; D_MiniMELF
D25: LED_CW; LED_1206_3216Metric
J1: 12-14V; TerminalBlock_MaiXu_MX126-5.0-02P_1x02_P5.00mm
J2: Left_Side; PinSocket_2x12_P2.54mm_Vertical
J3: Right_Side; PinSocket_2x12_P2.54mm_Vertical
J4: USB_A; USB_A_Wuerth_614004134726_Horizontal
J5: PTT_OUT; PinHeader_1x02_P2.54mm_Vertical
J10: 24-27V; TerminalBlock_MaiXu_MX126-5.0-02P_1x02_P5.00mm
J13, J14, J15, J16: MountHole; MountingHole_3.2mm_M3_DIN965_Pad
J17: I2C; PinHeader_1x04_P2.54mm_Vertical
J18: CW; Jack_3.5mm_CUI_SJ-3523-SMT_Horizontal
J19: UART0; PinHeader_1x04_P2.54mm_Vertical
J20: RS232; PinHeader_1x04_P2.54mm_Vertical
K1: TIANBO-HJR-4102-L; Relay_SPDT_CUI_SR5
Q1: BC817; SOT-23
R1, R2, R3, R4, R32: 1k; R_1206_3216Metric
R14, R15: 3k; R_1206_3216Metric
R33: 220; C_1206_3216Metric
U1: K7805-500R3; TO-220-3_Vertical
U15: LTV-817S; SMDIP-4_W9.53mm
U16: MAX232; SOIC-16_3.9x9.9mm_P1.27mm

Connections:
+5V: C7.1, C8.1, C9.1, C10.1, C11.1, C12.1, C17.2, J2.1, J3.2, J3.4, J4.1 (VBUS), J17.1, J19.1, J20.1, R2.2, R14.2, R15.2, U1.3 (VO), U16.16 (VCC); also elsewhere on the board
+12V: C1.1, C2.1, C3.1, C4.1, C5.1, C6.1, D1.1 (K), D5.1 (K), K1.A1, U1.1 (VI); also elsewhere on the board
+24V: C29.1, C30.1, D8.1 (K); also elsewhere on the board
DM1: J2.5; also elsewhere on the board
DM2: J2.9, J4.2 (D-)
DP1: J2.3; also elsewhere on the board
DP2: J2.7, J4.3 (D+)
GND: C1.2, C2.2, C3.2, C4.2, C5.2, C6.2, C7.2, C8.2, C9.2, C10.2, C11.2, C12.2, C29.2, C30.2, C33.2, D2.1 (K), D3.1 (K), D4.1 (K), D25.1 (K), J1.2, J2.23, J2.24, J3.6, J3.9, J3.14, J3.20, J4.4 (GND), J4.5 (Shield), J10.2, J13.1 (Pin_1_1), J14.1 (Pin_1_1), J15.1 (Pin_1_1), J16.1 (Pin_1_1), J17.4, J19.4, J20.4, Q1.2 (E), U1.2 (GND), U15.2, U16.15 (GND); also elsewhere on the board
unnamed: D1.2 (A), J1.1
unnamed: D2.2 (A), R1.1
unnamed: D3.2 (A), R2.1
unnamed: D4.2 (A), R3.1
unnamed: D5.2 (A), K1.A2, Q1.3 (C)
unnamed: D8.2 (A), J10.1
unnamed: D25.2 (A), R32.1
unnamed: J5.2 (Ext), K1.14
unnamed: J5.1 (In), K1.11
unnamed: J18.S, U15.3
unnamed: J18.T, U15.4
unnamed: Q1.1 (B), R4.2
unnamed: R33.2, U15.1
unnamed: C15.1, U16.1 (C1+)
unnamed: C15.2, U16.3 (C1-)
unnamed: C16.1, U16.4 (C2+)
unnamed: C16.2, U16.5 (C2-)
unnamed: C17.1, U16.2 (VS+)
unnamed: C33.1, U16.6 (VS-)
PA0: J3.11
PA1: J3.22
PA2: J3.13
PA3: J3.15
PA6: J3.12
PC0: J3.19
PC1: J3.21, R32.2, R33.1
PC2: J3.23, R1.2
PC3: J3.24, R3.2, R4.1
PG8: J3.16
PG9: J3.18
PG11: J3.7
RXD: J20.2, U16.13 (R1IN)
SCL: J3.5, J17.3, R15.1; also elsewhere on the board
SDA: J3.3, J17.2, R14.1; also elsewhere on the board
TXD: J20.3, U16.14 (T1OUT)
UART0_RX: J2.18, J19.2
UART0_TX: J2.20, J19.3
UART1_RX: J3.10, U16.12 (R1OUT)
UART1_TX: J3.8, U16.11 (T1IN)

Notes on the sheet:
NanoPi Neo

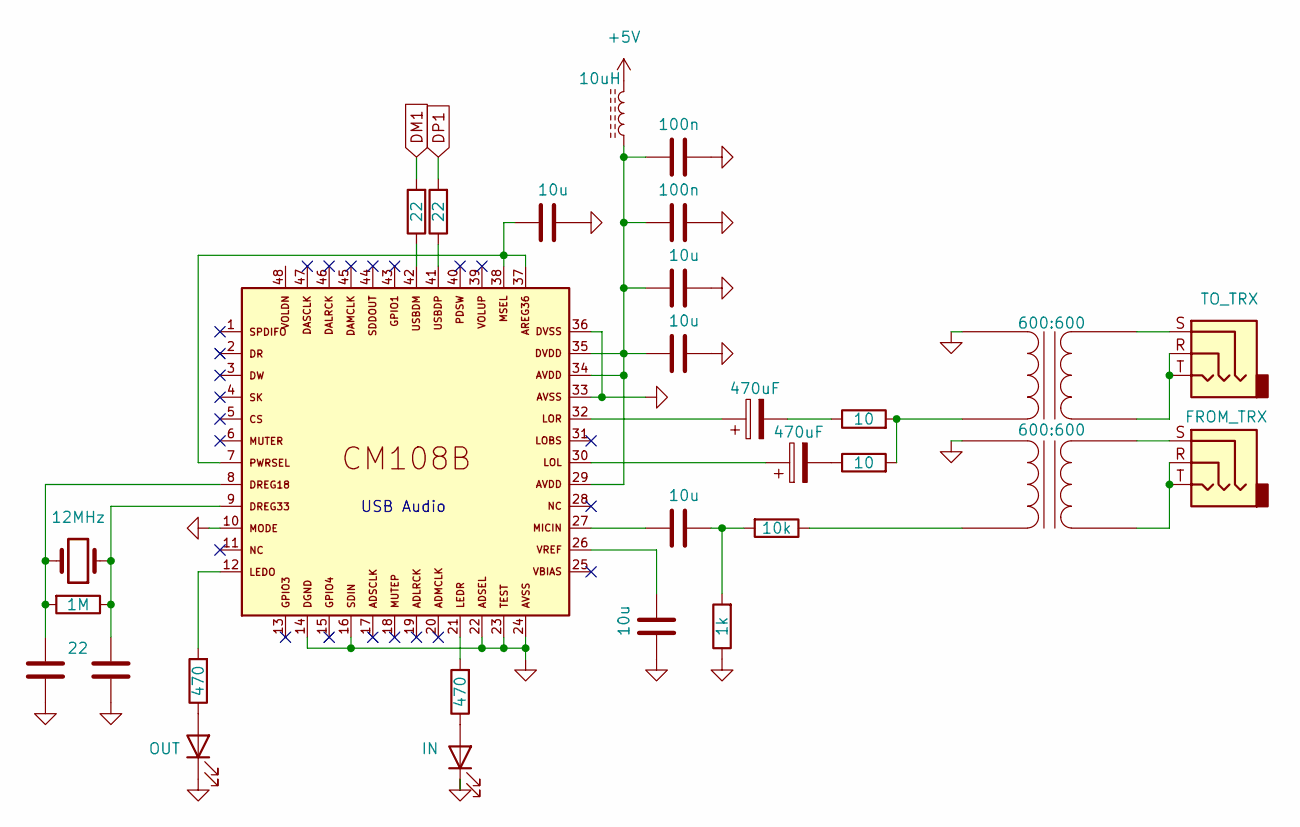
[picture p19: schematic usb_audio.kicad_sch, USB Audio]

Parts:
C18, C19: 22; C_1206_3216Metric_Pad1.33x1.80mm_HandSolder
C20, C21, C24, C25, C26: 10u; C_1206_3216Metric_Pad1.33x1.80mm_HandSolder
C22, C23: 100n; C_1206_3216Metric
C27, C28: 470uF; CP_Radial_D5.0mm_P2.50mm
D6: OUT; LED_1206_3216Metric
D7: IN; LED_1206_3216Metric
J8: TO_TRX; Jack_3.5mm_CUI_SJ-3523-SMT_Horizontal
J9: FROM_TRX; Jack_3.5mm_CUI_SJ-3523-SMT_Horizontal
L4: 10uH; R_1206_3216Metric
R5: 1M; R_1206_3216Metric
R6, R9: 470; R_1206_3216Metric
R7, R8: 22; R_1206_3216Metric
R10: 1k; R_1206_3216Metric
R11: 10k; R_1206_3216Metric
R12, R13: 10; R_1206_3216Metric
T1, T2: 600:600; Transformer_NF_ETAL_1-1_P1200
U8: CM108B; LQFP-48_7x7mm_P0.5mm
Y1: 12MHz; Crystal_HC18-U_Vertical

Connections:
+5V: L4.2; also elsewhere on the board
DM1: R7.2; also elsewhere on the board
DP1: R8.2; also elsewhere on the board
GND: C18.1, C19.1, C20.2, C21.1, C22.2, C23.2, C24.2, C25.2, D6.1 (K), D7.1 (K), R10.1, T1.1 (AA), T2.1 (AA), U8.10, U8.14, U8.16, U8.22, U8.23, U8.24, U8.33, U8.36; also elsewhere on the board
unnamed: C18.2, R5.2, U8.8, Y1.2
unnamed: C19.2, R5.1, U8.9, Y1.1
unnamed: C20.1, U8.7, U8.37, U8.38
unnamed: C21.2, U8.26
unnamed: C22.1, C23.1, C24.1, C25.1, L4.1, U8.29, U8.34, U8.35
unnamed: C26.1, U8.27
unnamed: C26.2, R10.2, R11.2
unnamed: C27.1, U8.32
unnamed: C27.2, R12.1
unnamed: C28.1, U8.30
unnamed: C28.2, R13.1
unnamed: D6.2 (A), R6.1
unnamed: D7.2 (A), R9.1
unnamed: R6.2, U8.12
unnamed: R7.1, U8.42
unnamed: R8.1, U8.41
unnamed: R9.2, U8.21
unnamed: R12.2, R13.2, T1.3 (AB)
unnamed: J8.R, J8.T, T1.4 (SA)
unnamed: J8.S, T1.6 (SB)
unnamed: R11.1, T2.3 (AB)
unnamed: J9.R, J9.T, T2.4 (SA)
unnamed: J9.S, T2.6 (SB)

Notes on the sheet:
USB Audio

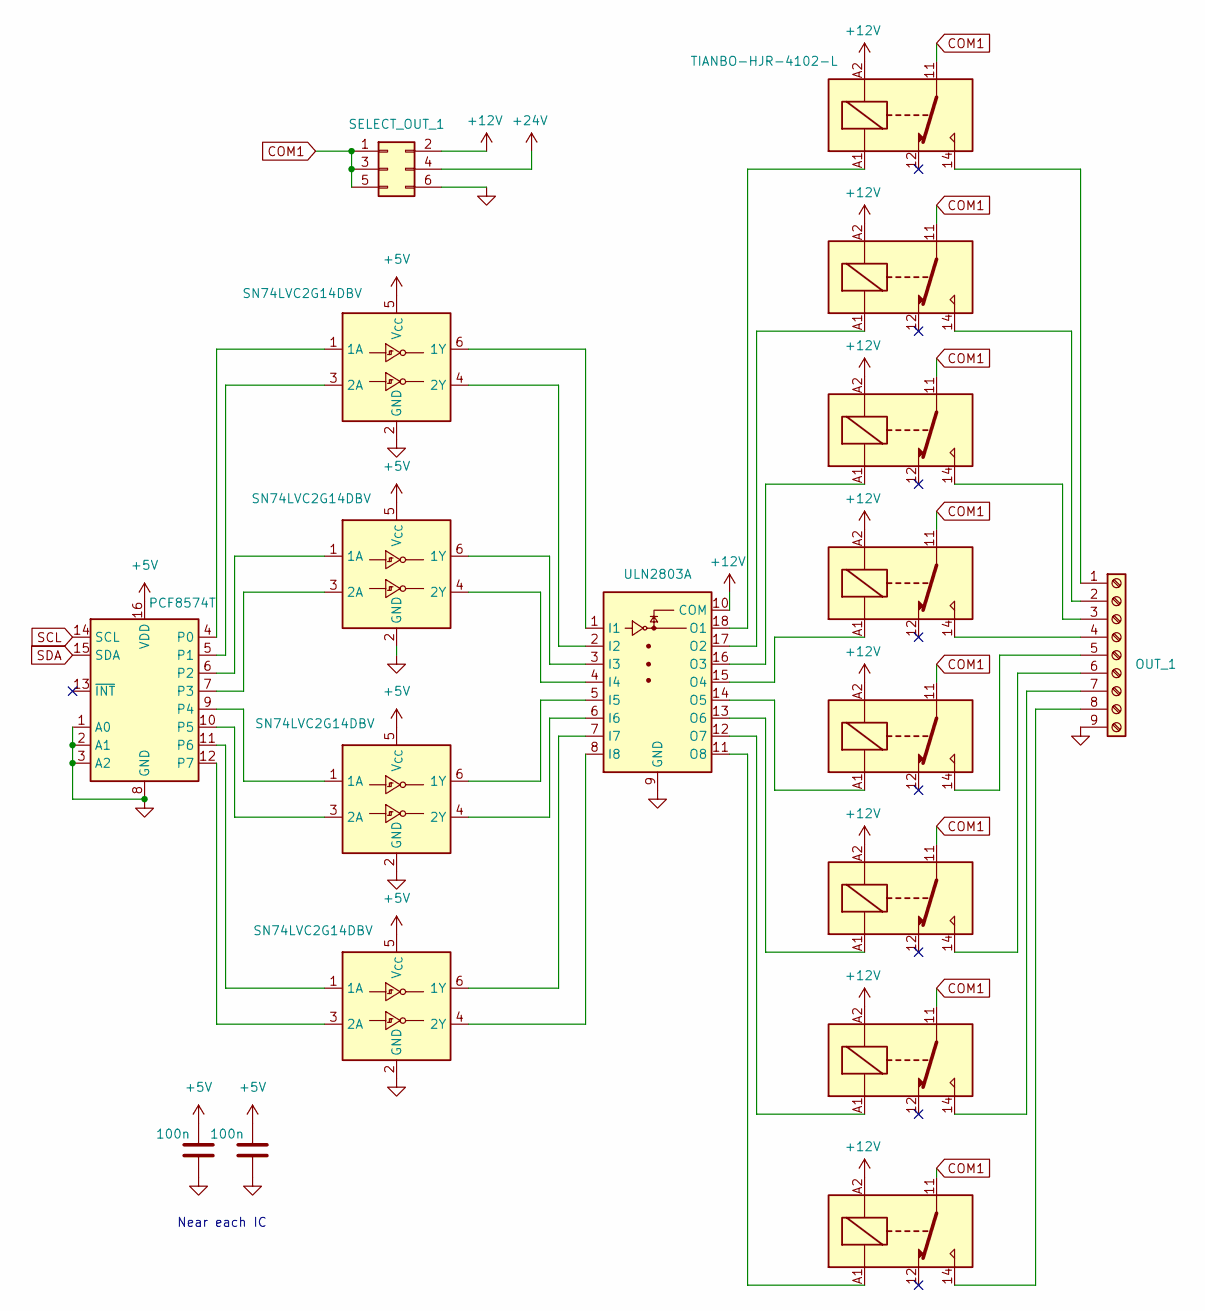
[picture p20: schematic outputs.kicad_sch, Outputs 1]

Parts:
C13, C14: 100n; C_1206_3216Metric
J7: OUT_1; TerminalBlock_MaiXu_MX126-5.0-09P_1x09_P5.00mm
J11: SELECT_OUT_1; PinHeader_2x03_P2.54mm_Vertical
K2, K18, K19, K20, K21, K22, K23, K24: TIANBO-HJR-4102-L; Relay_SPDT_CUI_SR5
U2: PCF8574T; SOIC-16W_7.5x10.3mm_P1.27mm
U3, U4, U5, U6: SN74LVC2G14DBV; SOT-23-6
U7: ULN2803A; SOIC-18W_7.5x11.6mm_P1.27mm

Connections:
+5V: C13.1, C14.1, U2.16 (VDD), U3.5 (V_{CC}), U4.5 (V_{CC}), U5.5 (V_{CC}), U6.5 (V_{CC}); also elsewhere on the board
+12V: J11.2, K2.A2, K18.A2, K19.A2, K20.A2, K21.A2, K22.A2, K23.A2, K24.A2, U7.10 (COM); also elsewhere on the board
+24V: J11.4; also elsewhere on the board
COM1: J11.1, J11.3, J11.5, K2.11, K18.11, K19.11, K20.11, K21.11, K22.11, K23.11, K24.11
GND: C13.2, C14.2, J7.9, J11.6, U2.1 (A0), U2.2 (A1), U2.3 (A2), U2.8 (GND), U3.2 (GND), U4.2 (GND), U5.2 (GND), U6.2 (GND), U7.9 (GND); also elsewhere on the board
unnamed: J7.1, K19.14
unnamed: J7.2, K2.14
unnamed: J7.3, K20.14
unnamed: J7.4, K18.14
unnamed: J7.5, K21.14
unnamed: J7.6, K24.14
unnamed: J7.7, K22.14
unnamed: J7.8, K23.14
unnamed: U2.4 (P0), U3.1 (1A)
unnamed: U2.5 (P1), U3.3 (2A)
unnamed: U2.6 (P2), U4.1 (1A)
unnamed: U2.7 (P3), U4.3 (2A)
unnamed: U2.9 (P4), U5.1 (1A)
unnamed: U2.10 (P5), U5.3 (2A)
unnamed: U2.11 (P6), U6.1 (1A)
unnamed: U2.12 (P7), U6.3 (2A)
unnamed: U3.6 (1Y), U7.1 (I1)
unnamed: U3.4 (2Y), U7.2 (I2)
unnamed: U4.6 (1Y), U7.3 (I3)
unnamed: U4.4 (2Y), U7.4 (I4)
unnamed: U5.6 (1Y), U7.5 (I5)
unnamed: U5.4 (2Y), U7.6 (I6)
unnamed: U6.6 (1Y), U7.7 (I7)
unnamed: U6.4 (2Y), U7.8 (I8)
unnamed: K19.A1, U7.18 (O1)
unnamed: K2.A1, U7.17 (O2)
unnamed: K20.A1, U7.16 (O3)
unnamed: K18.A1, U7.15 (O4)
unnamed: K21.A1, U7.14 (O5)
unnamed: K24.A1, U7.13 (O6)
unnamed: K22.A1, U7.12 (O7)
unnamed: K23.A1, U7.11 (O8)
SCL: U2.14 (SCL); also elsewhere on the board
SDA: U2.15 (SDA); also elsewhere on the board

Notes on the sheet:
Near each IC

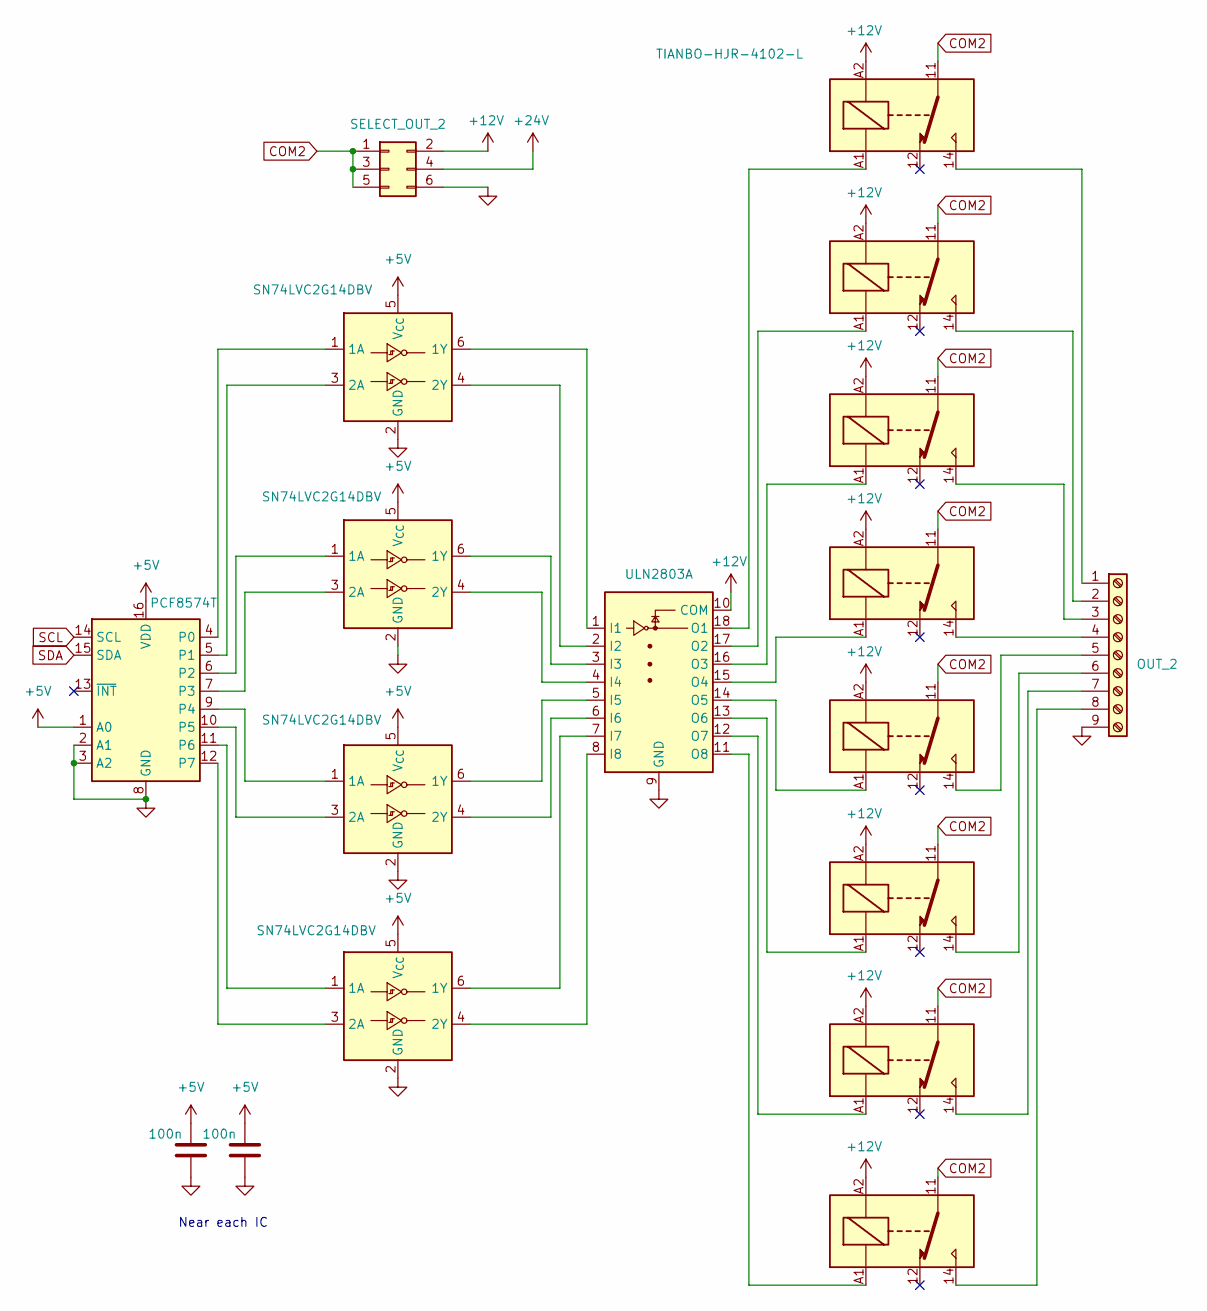
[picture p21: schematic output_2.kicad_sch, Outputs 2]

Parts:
C31, C32: 100n; C_1206_3216Metric
J6: SELECT_OUT_2; PinHeader_2x03_P2.54mm_Vertical
J12: OUT_2; TerminalBlock_MaiXu_MX126-5.0-09P_1x09_P5.00mm
K3, K4, K5, K6, K7, K8, K9, K10: TIANBO-HJR-4102-L; Relay_SPDT_CUI_SR5
U9: PCF8574T; SOIC-16W_7.5x10.3mm_P1.27mm
U10, U11, U12, U13: SN74LVC2G14DBV; SOT-23-6
U14: ULN2803A; SOIC-18W_7.5x11.6mm_P1.27mm

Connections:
+5V: C31.1, C32.1, U9.1 (A0), U9.16 (VDD), U10.5 (V_{CC}), U11.5 (V_{CC}), U12.5 (V_{CC}), U13.5 (V_{CC}); also elsewhere on the board
+12V: J6.2, K3.A2, K4.A2, K5.A2, K6.A2, K7.A2, K8.A2, K9.A2, K10.A2, U14.10 (COM); also elsewhere on the board
+24V: J6.4; also elsewhere on the board
COM2: J6.1, J6.3, J6.5, K3.11, K4.11, K5.11, K6.11, K7.11, K8.11, K9.11, K10.11
GND: C31.2, C32.2, J6.6, J12.9, U9.2 (A1), U9.3 (A2), U9.8 (GND), U10.2 (GND), U11.2 (GND), U12.2 (GND), U13.2 (GND), U14.9 (GND); also elsewhere on the board
unnamed: J12.1, K10.14
unnamed: J12.2, K3.14
unnamed: J12.3, K4.14
unnamed: J12.4, K5.14
unnamed: J12.5, K6.14
unnamed: J12.6, K7.14
unnamed: J12.7, K8.14
unnamed: J12.8, K9.14
unnamed: U9.4 (P0), U10.1 (1A)
unnamed: U10.6 (1Y), U14.1 (I1)
unnamed: U9.5 (P1), U10.3 (2A)
unnamed: U10.4 (2Y), U14.2 (I2)
unnamed: U9.6 (P2), U11.1 (1A)
unnamed: U11.6 (1Y), U14.3 (I3)
unnamed: U9.7 (P3), U11.3 (2A)
unnamed: U11.4 (2Y), U14.4 (I4)
unnamed: U9.9 (P4), U12.1 (1A)
unnamed: U12.6 (1Y), U14.5 (I5)
unnamed: U9.10 (P5), U12.3 (2A)
unnamed: U12.4 (2Y), U14.6 (I6)
unnamed: U9.11 (P6), U13.1 (1A)
unnamed: U13.6 (1Y), U14.7 (I7)
unnamed: U9.12 (P7), U13.3 (2A)
unnamed: U13.4 (2Y), U14.8 (I8)
unnamed: K10.A1, U14.18 (O1)
unnamed: K3.A1, U14.17 (O2)
unnamed: K4.A1, U14.16 (O3)
unnamed: K5.A1, U14.15 (O4)
unnamed: K6.A1, U14.14 (O5)
unnamed: K7.A1, U14.13 (O6)
unnamed: K8.A1, U14.12 (O7)
unnamed: K9.A1, U14.11 (O8)
SCL: U9.14 (SCL); also elsewhere on the board
SDA: U9.15 (SDA); also elsewhere on the board

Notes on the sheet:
Near each IC

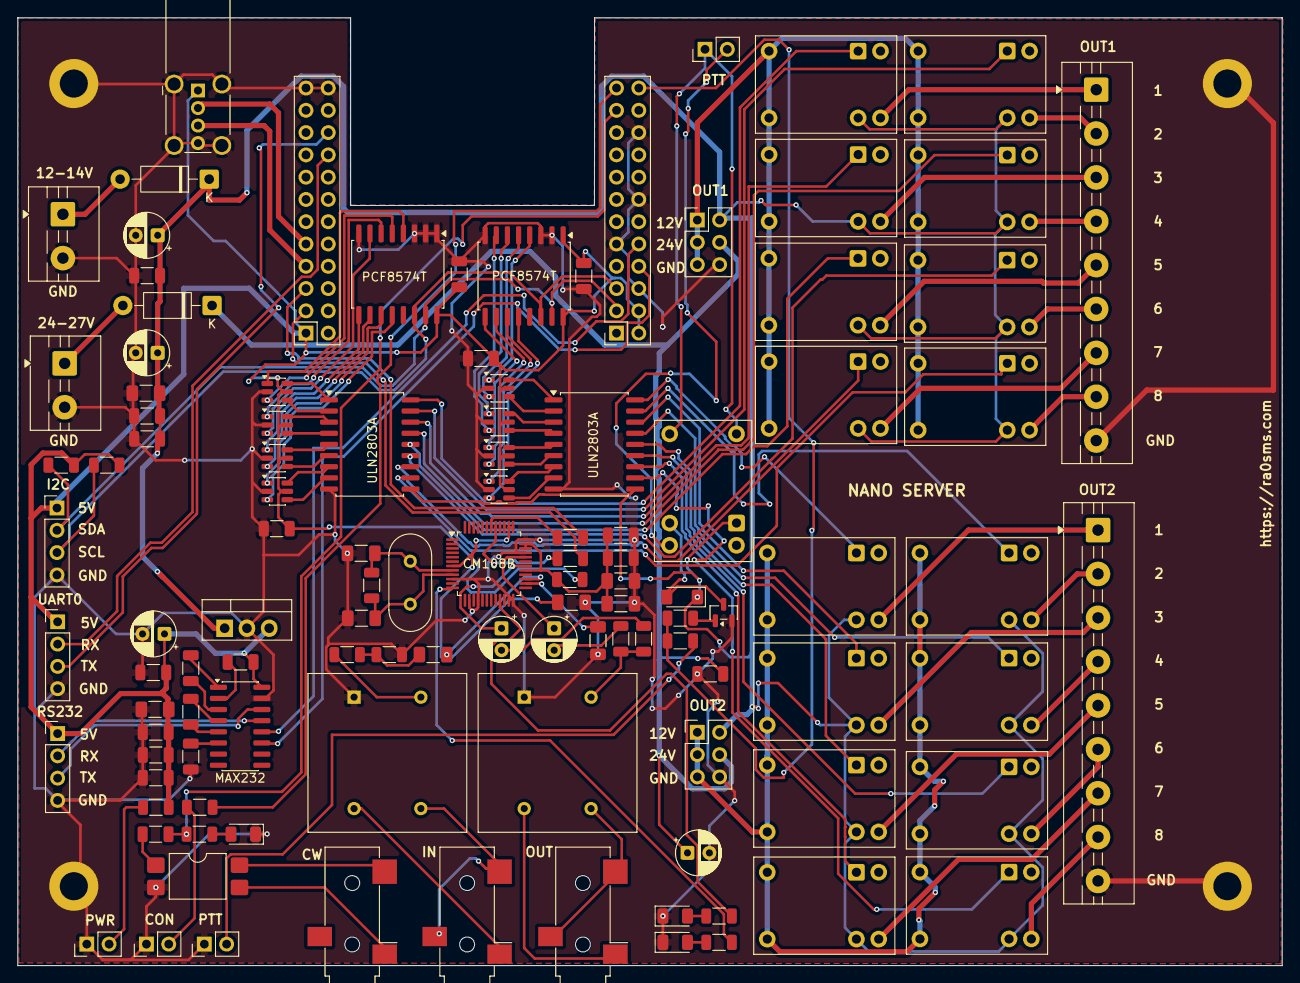
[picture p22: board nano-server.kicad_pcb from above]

Board: 2 copper layers, 144.1 x 108.1 mm, 117 parts (0 on the bottom side), 127 nets.

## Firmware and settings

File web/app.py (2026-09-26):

#!/usr/bin/python3
import asyncio
import glob
import hmac
import ipaddress
import json
import math
import os
import re
import secrets
import socket
import subprocess
import threading
import time
from pathlib import Path

import requests
import serial
from flask import (
    Flask,
    Response,
    jsonify,
    redirect,
    render_template,
    render_template_string,
    request,
    session,
    stream_with_context,
)
from smbus2 import SMBus

# ================= CONFIGURATION =================
app = Flask(__name__)

# Secret key used to sign the session cookie. A hardcoded key baked into
# the source would let anyone who reads the code forge a valid "auth"
# session cookie and bypass /login entirely, so it's generated once and
# persisted next to password.txt instead.
_SECRET_KEY_FILE = Path(__file__).with_name("secret_key.txt")
if _SECRET_KEY_FILE.exists():
    app.secret_key = _SECRET_KEY_FILE.read_text().strip()
else:
    app.secret_key = secrets.token_hex(32)
    _SECRET_KEY_FILE.write_text(app.secret_key)
    try:
        os.chmod(_SECRET_KEY_FILE, 0o600)
    except Exception:
        pass

# Don't send the session cookie with cross-site requests, so a page on another
# site can't drive the panel (toggle relays etc.) through the user's login.
app.config["SESSION_COOKIE_SAMESITE"] = "Lax"

# Password
_PASSWORD_FILE = Path(__file__).with_name("password.txt")
PASSWORD = _PASSWORD_FILE.read_text().strip() if _PASSWORD_FILE.exists() else "1234"

# I2C for relays (PCF8574T expanders). The relay board is optional: the web
# panel must keep running even when no I2C module is connected (e.g. during a
# bare-NanoPi setup). So opening the bus AND probing both expander addresses
# are wrapped in try/except — if anything fails, `bus` stays None and every
# relay write is skipped instead of crashing the service.
ADDR1 = 0x20
ADDR2 = 0x21

bus = None
try:
    _probe_bus = SMBus(0)
    # Probing writes the initial all-off state, so this is safe on real hardware.
    _probe_bus.write_byte(ADDR1, 0xFF)
    _probe_bus.write_byte(ADDR2, 0xFF)
    bus = _probe_bus
    print("[relay] I2C OK: relay board detected")
except Exception as _e:
    print(f"Warning: I2C / relay board not available ({_e}); relay control disabled")

state1 = 0xFF
state2 = 0xFF

# Guards state1/state2 (and the band-relay tracking below): they are changed
# from Flask request threads (manual toggle) and from the CAT serial thread
# (automatic band switching). Reentrant, since toggling = toggle_relay + apply.
relay_lock = threading.RLock()

# ================= TRANSFER CONFIG =================
TRX_CONFIG_FILE = Path(__file__).with_name("trx_config.json")

default_trx_config = {
    # The CAT serial port is chosen by the user on the web Settings tab; an
    # empty default means the TRX stays offline until a port is selected.
    "serial_port": "",
    "baudrate": 19200,
    "protocol": "Icom",
    "radio_addr": 0x70,
    # CI-V controller address used by the external programs (flrig, JTDX,
    # Hamlib — 0xE0 is their near-universal default).
    "ctrl_addr": 0xE0,
    # CI-V controller address the server itself uses for its own polls and web
    # UI commands. It differs from ctrl_addr on purpose: the radio replies to
    # the sender's address, so replies meant for the server can be told apart
    # and are NOT forwarded to external programs, which would otherwise take
    # them as answers to their own requests. Set it equal to ctrl_addr to get
    # the old behavior (everything forwarded).
    "server_addr": 0xE1,
    "tcp_port": 3001,
    # Extra IPs allowed to connect to the CAT TCP port, besides 127.0.0.1 and
    # the client IP from client_ip.cfg.
    "tcp_allowed_ips": [],
    "enabled": True,
    "uart1_enabled": True,
    "uart1_port": "/dev/ttyS1",
}

trx_config = {}

# Radio state
radio_state = {
    "freq": 0,
    "band": "Unknown",
    "online": False,
    "last_rx": 0,
    "mode": "Unknown",
}

# Serial and async components
ser = None
ser_uart1 = None
clients = set()
decoder = None
loop = None

# Timestamp (time.time()) of the most recent CAT frame an external controller
# sent toward the radio — either through the UART1 transparent relay or a TCP
# client. The poller uses this to tell whether an external program currently
# owns the CAT port, so the server knows when it is safe to run its own
# CI-V / IF polling without corrupting the stream.
external_cat_time = 0.0

# Frame-collision guard: how long after an external program writes a frame the
# server must wait before injecting its own query, so we never interleave
# mid-frame. Kept tiny (0.3 s) so the server still polls freely between external
# bursts and the web frequency stays live even with an idle CAT bridge.
EXTERNAL_CAT_TIMEOUT = 0.3

# How recently (seconds) the radio must have reported the active frequency for
# the server to treat it as "already fresh" (i.e. an external program like
# flrig is polling it through the relay, or the radio sends transceive reports)
# and skip its own poll. Larger than the poll cadence.
RADIO_FRESH_TIMEOUT = 2.0

# Serialize writes to the CAT port (ser). pyserial write() is NOT thread-safe:
# multiple threads (uart1_reader, tcp_client, poller) write to the same port,
# and interleaved writes can corrupt the CAT frame and desynchronize the
# transceiver. A single lock prevents mid-byte interleaving and also guards
# the close+reopen cycle during automatic error recovery.
ser_lock = threading.Lock()

# ================= RELAY FUNCTIONS =================


def apply():
    """Write the relay states to the I2C expanders. No-op if the I2C bus was not
    available at startup, and tolerant of a mid-run bus error (e.g. the relay
    board being unplugged), so a missing/disconnected I2C module never crashes
    the web service."""
    if bus is None:
        return
    try:
        with relay_lock:
            bus.write_byte(ADDR1, state1)
            bus.write_byte(ADDR2, state2)
    except Exception as e:
        print(f"[relay] I2C write failed: {e} (relay board disconnected?)")


def get_state():
    with relay_lock:
        s1, s2 = state1, state2
    bits = []
    for i in range(8):
        bits.append(1 if (s1 & (1 << i)) == 0 else 0)
    for i in range(8):
        bits.append(1 if (s2 & (1 << i)) == 0 else 0)
    return bits


def set_relay(n, on):
    global state1, state2
    if n < 8:
        if on:
            state1 &= ~(1 << n)
        else:
            state1 |= 1 << n
    else:
        n -= 8
        if on:
            state2 &= ~(1 << n)
        else:
            state2 |= 1 << n


def toggle_relay(n):
    global state1, state2
    reason = ptt_lock_reason()
    if reason:
        print(f"🔒 PTT {reason} — relay toggle blocked")
        return

    bits = get_state()
    group = 0 if n < 8 else 1
    bit = n if n < 8 else n - 8
    mode = config["group_mode"][group]

    if mode == "switch":
        if group == 0:
            state1 = 0xFF & ~(1 << bit)
        else:
            state2 = 0xFF & ~(1 << bit)
        return

    set_relay(n, not bits[n])


# ================= RELAY CONFIG =================

CONFIG_FILE = Path(__file__).with_name("config.json")

default_config = {
    "names": [f"Relay {i + 1}" for i in range(16)],
    "group_mode": ["toggle", "toggle"],
}

config = {}


def load_relay_config():
    global config
    if CONFIG_FILE.exists():
        try:
            with open(CONFIG_FILE, "r") as f:
                config = json.load(f)
            if "names" not in config:
                config["names"] = default_config["names"]
            if "group_mode" not in config:
                config["group_mode"] = default_config["group_mode"]
        except Exception:
            config = default_config.copy()
    else:
        config = default_config.copy()
        save_relay_config()


def save_relay_config():
    tmp = CONFIG_FILE.with_suffix(".tmp")
    with open(tmp, "w") as f:
        json.dump(config, f, indent=2)
    os.replace(tmp, CONFIG_FILE)


# ================= AMATEUR BAND DEFINITIONS =================
# Single source of truth for band ranges: used by the default band relay
# rules, freq_to_band() and the TRX "set band" control, so they can't drift
# out of sync with each other.
# Each entry: (from_khz, to_khz, name, default_target_freq_hz)
AMATEUR_BANDS = [
    (1800, 2000, "160m", 1840000),
    (3500, 3800, "80m", 3573000),
    (7000, 7200, "40m", 7074000),
    (10100, 10150, "30m", 10136000),
    (14000, 14350, "20m", 14074000),
    (18068, 18168, "17m", 18100000),
    (21000, 21450, "15m", 21074000),
    (24890, 24990, "12m", 24915000),
    (28000, 29700, "10m", 28074000),
    (50000, 54000, "6m", 50313000),
]

# ================= BAND RELAY RULES =================

BAND_RULES_FILE = Path(__file__).with_name("band_rules.json")

# Default rules: one per amateur band
default_band_rules = [{"from": f, "to": t, "relays": []} for f, t, _, _ in AMATEUR_BANDS]

band_rules = []
band_relay_enabled = True  # Global toggle for automatic relay switching


def validate_band_rules(rules):
    """Check band relay rules. Returns (normalized_rules, None) or
    (None, error message).

    Rules are evaluated on every CAT frequency reading, so a malformed rule
    (e.g. a string "from") must never get into band_rules: comparing it with
    the frequency would raise inside the CAT reader thread."""
    if not isinstance(rules, list):
        return None, "expected an array of rules"
    normalized = []
    for i, rule in enumerate(rules, 1):
        if not isinstance(rule, dict) or not {"from", "to", "relays"} <= rule.keys():
            return None, f"rule {i}: must have 'from', 'to' and 'relays'"
        lo, hi, relays = rule["from"], rule["to"], rule["relays"]
        for v in (lo, hi):
            # bool is a subclass of int; NaN/Infinity are accepted by json.loads
            if isinstance(v, bool) or not isinstance(v, (int, float)) or not math.isfinite(v):
                return None, f"rule {i}: 'from' and 'to' must be numbers (kHz)"
        if not 0 <= lo < hi:
            return None, f"rule {i}: 'from' must be >= 0 and less than 'to'"
        if not isinstance(relays, list):
            return None, f"rule {i}: 'relays' must be an array"
        for r in relays:
            if isinstance(r, bool) or not isinstance(r, int) or not 0 <= r <= 15:
                return None, f"rule {i}: invalid relay index {r!r}"
        normalized.append({"from": lo, "to": hi, "relays": relays})
    return normalized, None


def load_band_rules():
    global band_rules
    if BAND_RULES_FILE.exists():
        try:
            with open(BAND_RULES_FILE, "r") as f:
                rules, error = validate_band_rules(json.load(f))
            if error:
                raise ValueError(error)
            band_rules = rules
        except Exception as e:
            # Keep the unreadable file for the user instead of silently
            # losing their rules when the defaults are written over it.
            backup = BAND_RULES_FILE.with_suffix(".json.invalid")
            print(f"[bandrelay] ⚠️ {BAND_RULES_FILE.name} is invalid ({e}); "
                  f"using default rules, old file saved as {backup.name}")
            try:
                os.replace(BAND_RULES_FILE, backup)
            except Exception:
                pass
            band_rules = default_band_rules.copy()
            save_band_rules()
    else:
        band_rules = default_band_rules.copy()
        save_band_rules()


def save_band_rules():
    tmp = BAND_RULES_FILE.with_suffix(".tmp")
    with open(tmp, "w") as f:
        json.dump(band_rules, f, indent=2)
    os.replace(tmp, BAND_RULES_FILE)


def apply_band_rules(freq_hz):
    """Check band rules and activate relays for the given frequency (in Hz).
    Returns the list of relay indices that should be ON.
    Rules: from <= freq_khz < to (lower bound inclusive, upper bound exclusive).
    """
    if not band_rules or not freq_hz:
        return []

    # Convert Hz to kHz for rule matching
    freq_khz = freq_hz / 1000

    # Find matching rules (a frequency can match multiple rules)
    active_relays = set()
    for rule in band_rules:
        if rule["from"] <= freq_khz < rule["to"]:
            for r in rule.get("relays", []):
                if 0 <= r <= 15:
                    active_relays.add(r)

    return sorted(active_relays)


def _managed_relay_groups():
    """Return the set of relay groups (0 = relays 1-8, 1 = relays 9-16) that are
    referenced by any band rule. Groups not referenced by any rule are left
    completely untouched by automatic switching, so their relays can still be
    selected manually without being reset on every frequency change."""
    managed = set()
    for rule in band_rules:
        for r in rule.get("relays", []):
            if 0 <= r <= 15:
                managed.add(0 if r < 8 else 1)
    return managed


def set_relays_for_frequency(freq_hz):
    """Set relays according to band rules for the given frequency.

    Only the relay group(s) actually referenced by the band rules are reset and
    re-selected (auto-managed). Relays in any other group keep their current
    state, so e.g. if auto-switching only uses relays 1-8, then relays 9-16 are
    never touched automatically and can be selected manually.

    Returns the list of relays switched on, or None if switching is disabled
    or blocked by PTT (nothing was changed).
    """
    global state1, state2
    if not band_relay_enabled:
        return None

    reason = ptt_lock_reason()
    if reason:
        print(f"🔒 PTT {reason} — band relay switching blocked")
        return None

    target = apply_band_rules(freq_hz)
    managed = _managed_relay_groups()

    with relay_lock:
        # Only reset the groups that are auto-managed by the band rules. The other
        # group byte is left as-is so a manually-selected relay there is preserved.
        if 0 in managed:
            state1 = 0xFF
        if 1 in managed:
            state2 = 0xFF

        for r in target:
            set_relay(r, True)

        apply()
    return target


# Automatic switching only acts when the frequency moves into a range with a
# DIFFERENT relay set, and only once two readings at least
# BAND_RELAY_CONFIRM_SECONDS apart agree. So a single corrupted CAT frame
# can't flip the antenna, tuning across a range boundary doesn't chatter the
# relays, and a relay toggled by hand inside an auto-managed group stays as set
# until the next band change instead of being reset on every CAT reading.
BAND_RELAY_CONFIRM_SECONDS = 0.3
band_relay_applied = None  # tuple of relays last applied automatically; None = apply on next reading
band_relay_pending = None  # (target tuple, time.monotonic() first seen) awaiting confirmation


def reset_band_relay_tracking():
    """Forget the last applied relay set, so the next frequency reading
    re-applies the rules (after rules are edited or auto-switching is
    re-enabled)."""
    global band_relay_applied, band_relay_pending
    with relay_lock:
        band_relay_applied = None
        band_relay_pending = None


def track_band_relays(freq_hz):
    """Called for every frequency the transceiver reports."""
    with relay_lock:
        _track_band_relays(freq_hz)


def _track_band_relays(freq_hz):
    global band_relay_applied, band_relay_pending
    if not band_relay_enabled:
        return
    target = tuple(apply_band_rules(freq_hz))
    if target == band_relay_applied:
        band_relay_pending = None
        return
    now = time.monotonic()
    if band_relay_pending is None or band_relay_pending[0] != target:
        band_relay_pending = (target, now)
        return
    if now - band_relay_pending[1] < BAND_RELAY_CONFIRM_SECONDS:
        return
    # Blocked by PTT -> stays pending and is applied on a reading after TX ends.
    if set_relays_for_frequency(freq_hz) is not None:
        band_relay_applied = target
        band_relay_pending = None


# ================= AUDIO & NETWORK CONFIG =================

# Audio/network paths (from web_config_server.py)
# Derive the project root from this file's own location so paths stay correct
# regardless of where the repo is installed (e.g. /home/pi/nano-server).
PROJECT_DIR = str(Path(__file__).resolve().parent.parent)
SERVER_IP_FILE = os.path.join(PROJECT_DIR, "server_ip.cfg")
CLIENT_IP_FILE = os.path.join(PROJECT_DIR, "client_ip.cfg")
AUDIO_CONFIG_FILE = os.path.join(PROJECT_DIR, "audio/audio_config.cfg")
PROFILES_DIR = os.path.join(PROJECT_DIR, "profiles")

# UDP Ping configuration
UDP_PORT = 5002
TIMEOUT = 1.0
CHECK_INTERVAL = 0.3
MAGIC_PHRASE = b"PING_RESPONSE"

# PTT status from combined_ptt_service (via UDP broadcast on port 5004). The
# service re-sends its current state every ~0.3 s as a heartbeat, so a missing
# heartbeat means the GPIO PTT state is unknown (service stopped/crashed, or
# this web panel just restarted) and relays must stay locked until it's known.
PTT_STATUS_PORT = 5004
PTT_STATUS_STALE_SECONDS = 1.5
ptt_active = False
ptt_status_time = 0.0  # time.monotonic() of the last PTT status packet

# Transmit state seen on the CAT line: TX/RX commands external programs (JTDX,
# WSJT-X, flrig) send through the relay, and the radio's own TX/RX reports.
# CAT PTT bypasses the GPIO PTT line entirely, so without this the relay lock
# would not know the radio is transmitting.
cat_tx_active = False


def ptt_lock_reason():
    """Why relay switching is blocked right now: 'gpio' (GPIO PTT on), 'cat'
    (radio transmitting via CAT), 'unknown' (no fresh PTT status from
    combined_ptt_service), or None when relays may be switched."""
    stale = time.monotonic() - ptt_status_time > PTT_STATUS_STALE_SECONDS
    if ptt_active and not stale:
        return "gpio"
    if cat_tx_active:
        return "cat"
    if stale:
        return "unknown"
    return None


def _set_cat_tx(active):
    global cat_tx_active
    if active != cat_tx_active:
        cat_tx_active = active
        print(f"[TRX] CAT PTT {'ON' if active else 'OFF'}")

# Client-app presence from combined_ptt_service (via UDP broadcast on port 5005).
# True only while the client software is actually sending control traffic — NOT
# merely reachable by ping to its IP.
CLIENT_STATUS_PORT = 5005
client_connected = False

# Global variables for status
current_rtt = None
last_update = None
status_active = False
status_thread = None
status_lock = threading.Lock()

# Ensure profiles directory exists
if not os.path.exists(PROFILES_DIR):
    os.makedirs(PROFILES_DIR)
# Ensure the profiles directory and its contents are writable by the process
if not os.access(PROFILES_DIR, os.W_OK):
    print(f"WARNING: {PROFILES_DIR} is not writable — profile save/delete will fail.")
    print("Fix: sudo chown -R pi:pi /home/pi/nano-server && sudo chmod -R u+rw /home/pi/nano-server")

# Audio ALSA controls — auto-detected

def _find_alsa_card():
    """Find the C-Media USB Audio Device card identifier.
    Returns the card ID (e.g., 'Device') or index (e.g., '1') as fallback.
    """
    try:
        with open("/proc/asound/cards", "r") as f:
            content = f.read()
        for line in content.splitlines():
            # Look for "C-Media" USB audio device first
            if "C-Media" in line:
                # Line format: " 1 [Device         ]: USB-Audio - ..."
                m = re.search(r'\[(\w+)\]', line)
                if m:
                    card_id = m.group(1)
                    return card_id
        # Second pass: any USB Audio device that isn't webcam
        for line in content.splitlines():
            if "USB Audio" in line and "webcam" not in line.lower():
                m = re.search(r'\[(\w+)\]', line)
                if m:
                    card_id = m.group(1)
                    return card_id
    except Exception as e:
        print(f"[audio] Error reading /proc/asound/cards: {e}")

    # Fallback: try to find any card that isn't audiocodec or webcam
    try:
        with open("/proc/asound/cards", "r") as f:
            content = f.read()
        for line in content.splitlines():
            m = re.search(r'\[(\w+)\]', line)
            if m:
                card_id = m.group(1)
                if card_id not in ("audiocodec", "webcam"):
                    return card_id
    except Exception:
        pass

    print("[audio] WARNING: using card 0 as fallback")
    return "0"
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

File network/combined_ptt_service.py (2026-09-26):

#!/usr/bin/python3
"""
Combined service: PTT + Client Monitor + Ping Responder + CW Keyer (Winkeyer)
=============================================================================
All GPIO lines are requested in a single gpiod.request_lines() call to avoid
conflicts between separate processes on the same gpiochip.

GPIO lines:
  - PC1 (line 65) — CW Keyer output (Winkeyer)
  - PC2 (line 66) — CON LED (client reachability)
  - PC3 (line 67) — PTT output

UDP ports:
  - 5001 — PTT commands ('0' / '1')
  - 5002 — Ping / RTT monitoring
  - 5003 — Winkeyer CW Keyer protocol

XML-RPC (compatible with PyWinKeyerSerial by K6GTE):
  - 6789 — k1elsendstring, setspeed, sendblended, tuneon/tuneoff, clearbuffer
"""

import os
import signal
import socket
import sys
import threading
import time
from xmlrpc.server import SimpleXMLRPCServer
from xmlrpc.server import SimpleXMLRPCRequestHandler

import gpiod

# --- Detect libgpiod API version (v2 vs v1) ---
try:
    from gpiod.line import Direction, Value  # libgpiod v2 exposes gpiod.line.*
    GPIOD_V2 = True
except ImportError:
    GPIOD_V2 = False  # libgpiod v1: gpiod is a single module (no gpiod.line)
if GPIOD_V2:
    ver = getattr(gpiod, "__version__", "unknown")
    print(f"ℹ️ Using libgpiod v2 bindings (gpiod {ver}).")
else:
    ver = getattr(gpiod, "VERSION", getattr(gpiod, "__version__", "unknown"))
    print(f"ℹ️ Using libgpiod v1 bindings (gpiod {ver}).")

# ================= CONFIGURATION =================

SCRIPT_DIR = os.path.dirname(os.path.abspath(__file__))
CLIENT_IP_FILE = os.path.join(SCRIPT_DIR, "..", "client_ip.cfg")

# === GPIO ===
CHIP_PATH = "/dev/gpiochip0"
LINE_CW = 65    # PC1 — CW Keyer output
LINE_CON = 66   # PC2 — CON LED
LINE_PTT = 67   # PC3 — PTT output
CONSUMER = "nano_server_combined"

# === UDP ===
SERVER_IP = "0.0.0.0"
PTT_PORT = 5001       # PTT commands
PING_PORT = 5002      # Ping / RTT
WK_PORT = 5003        # Winkeyer CW Keyer
XMLRPC_PORT = 6789    # XML-RPC (PyWinKeyerSerial compatible, default in not1mm)
TIMEOUT = 1.0
CHECK_INTERVAL = 0.3
MAGIC_PHRASE = b"PING_RESPONSE"

# === PTT Keepalive ===
PTT_KEEPALIVE_TIMEOUT = 0.5   # 500 ms — force PTT off if no packet received
PTT_KEEPALIVE_CHECK_INTERVAL = 0.1  # 100 ms — check loop granularity

# === Tune-mode watchdog ===
# The Winkeyer 0x1C command and the XML-RPC tuneon() call hold PTT/key down
# indefinitely until an explicit off command (0x1D / tuneoff()), with no
# renewal packets like the port-5001 keepalive protocol has. If the client
# that engaged tune mode disappears without releasing it, this caps how
# long the transmitter can be held keyed.
TUNE_MAX_HOLD_SECONDS = 60

# === PTT Status Broadcast (to web panel) ===
PTT_STATUS_PORT = 5004  # UDP port for broadcasting PTT status to web panel on localhost (on change + every CHECK_INTERVAL)

# === Client app presence detection ===
# The client application is considered "connected" while it keeps sending packets
# on its control ports (PTT 5001 / CW 5003) from the authorized client IP within
# CLIENT_PRESENCE_TIMEOUT. Unlike a ping to the client IP — which succeeds even
# after the user pressed "Disconnect" — this reflects whether the client software
# is actually active.
CLIENT_PRESENCE_TIMEOUT = 5.0     # seconds of silence before "disconnected"
CLIENT_STATUS_PORT = 5005         # UDP broadcast: client connected/disconnected -> web panel

# === CW defaults ===
WPM_DEFAULT = 20
WPM_MIN = 5
WPM_MAX = 99
MAX_BUFFER = 255

# === State ===
ptt_state = 0
client_ip = "0.0.0.0"
client_last_seen = 0.0       # monotonic timestamp of last packet from the client app
shutdown_flag = threading.Event()

# PTT keepalive tracking
ptt_keepalive_last = 0.0       # timestamp of last received PTT packet (monotonic)
ptt_keepalive_active = False   # True when we've received a "1" with keepalive flag
ptt_last_seq = 0               # last seen sequence number (for gap detection)
ptt_seq_gap_detected = False   # set True when a seq gap is found

# Tune-mode watchdog tracking: monotonic timestamp of when Winkeyer 0x1C /
# rpc_tuneon() last engaged PTT, or None when not in tune mode. Cleared
# whenever PTT turns off through any path (see set_ptt()).
tune_hold_start = None

# CW state
wpm = WPM_DEFAULT
cw_buffer = bytearray()
cw_sending = False
cw_send_lock = threading.Lock()

# === GPIO abstraction (works with both libgpiod v1 and v2) ===
class _GpioOutput:
    """Thin wrapper that lets the rest of the code write GPIO the same way
    regardless of whether libgpiod v1 or v2 is installed."""
    def __init__(self, chip_path, consumer, mapping):
        # mapping: {offset: initial_value(0/1)}
        self.v2 = GPIOD_V2
        self._v2_req = None
        self._v1_lines = {}
        if self.v2:
            cfg = {
                off: gpiod.LineSettings(
                    direction=Direction.OUTPUT,
                    output_value=Value.INACTIVE if init == 0 else Value.ACTIVE,
                )
                for off, init in mapping.items()
            }
            self._v2_req = gpiod.request_lines(
                chip_path, consumer=consumer, config=cfg
            )
        else:
            self._chip = gpiod.Chip(chip_path)
            for off, init in mapping.items():
                ln = self._chip.get_line(off)
                ln.request(
                    consumer=consumer,
                    type=gpiod.LINE_REQ_DIR_OUT,
                    default_vals=[init],
                )
                self._v1_lines[off] = ln

    def set_value(self, offset, value):
        if self.v2:
            self._v2_req.set_value(
                offset, Value.ACTIVE if value else Value.INACTIVE
            )
        else:
            self._v1_lines[offset].set_value(value)

    def release(self):
        if self.v2:
            self._v2_req.release()
        else:
            for ln in self._v1_lines.values():
                ln.release()


# === GPIO Setup — single request for all lines (both API versions) ===
try:
    gpio = _GpioOutput(
        CHIP_PATH,
        CONSUMER,
        {LINE_CW: 0, LINE_CON: 0, LINE_PTT: 0},
    )
    print("✅ GPIO lines initialized (CW=PC1, CON=PC2, PTT=PC3).")
except Exception as e:
    print(f"❌ GPIO initialization failed: {e}")
    sys.exit(1)


# ================= PTT FUNCTIONS =================


def read_allowed_ip(filename):
    global client_ip
    try:
        with open(filename, "r") as f:
            ip = f.read().strip()
            if not ip:
                print("⚠️ client_ip.cfg is empty — using 0.0.0.0")
                ip = "0.0.0.0"
            client_ip = ip
            print(f"✅ Allowed client IP: {client_ip}")
            return ip
    except Exception as e:
        print(f"❌ Error reading {filename}: {e}")
        client_ip = "0.0.0.0"
        return client_ip
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

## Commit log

2026-06-08 fix web config page
    [combined_ptt_service.py]
2026-06-08 fix web relay
2026-06-08 fix i2c permition
2026-06-10 fix web interface issuies
    [app.py]
2026-06-11 add KiCad files and fix readme
    [freerouting.dsn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]
2026-06-18 fix audio web interface issues
    [app.py]
2026-06-19 fix audio control tab
    [app.py]
2026-06-19 fix audio number of channel issue
    [app.py]
2026-06-19 fix audio capture issue
    [app.py]
2026-06-19 add band decoder for relay
2026-06-19 fix band plan boards
    [app.py]
2026-06-21 fix morse code issuies
    [combined_ptt_service.py]
2026-06-25 fix mode selection issue
    [app.py]
2026-06-25 fix trx tab finally
    [app.py]
2026-06-25 del some debug print()
2026-07-01 feat: add PTT lock — block relay switching during transmission
    - combined_ptt_service.py: broadcast PTT status via UDP on port 5004
    - web/app.py: listen for PTT status, block toggle_relay() and
    set_relays_for_frequency() when PTT is active
    - web/app.py: add /ptt/status API endpoint
    - web UI: visual relay button blocking (dimmed, not-allowed cursor)
    and client-side check before toggle
    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
2026-07-01 add UART1 translation CAT
2026-07-03 add UART list on settings tab
2026-07-03 add UART refresh button
2026-08-04 add cutoff audio filter for 50Hz
2026-08-04 add LPF 2700 Hz
2026-08-05 fix Kenwood potocol IF; responce
    [app.py]
2026-08-08 fix transaltion from TRX to ttyS1, add checbox in th UI
    [app.py]
2026-08-08 fix losing cat control through ttyS1
    [app.py]
2026-08-09 fix audio control saving and restore
    [app.py]
2026-08-09 fix some iisues with cat
    [app.py]
2026-08-10 fix some iisues with cat via ttyS1
    [app.py]
2026-08-19 fix schematic and gerbers
    [nano-server-B_Cu.gbr, nano-server-B_Mask.gbr, nano-server-B_Paste.gbr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]
2026-08-26 Fix security and protocol bugs in web panel and PTT/CW service
    web/app.py:
    - Generate and persist a random Flask secret_key instead of a hardcoded
    one, which let anyone reading the source forge a valid session cookie
    and bypass /login.
    - Fix path traversal in load_profile/delete_profile (name wasn't
    validated, unlike save_profile).
    - Use constant-time password comparison and add login rate limiting.
    - Fix Kenwood CAT parsing: wrong mode-digit offset in IF frames, wrong
    MD mode codes for FSK-R/invalid, and a malformed/wrongly-scaled AG
    (AF gain) command, per the Kenwood PC control command reference.
    - Deduplicate BCD frequency encoding, amateur band tables, and the
    Kenwood mode ma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
    [app.py, combined_ptt_service.py]
2026-08-30 fix audio settings save
    [app.py]
2026-08-30 first fix for this branch
    [app.py]
2026-08-30 release v1.1.1: fix update flow blocked by its own runtime config files
    web/config.json and audio/audio_config.cfg were tracked in git and rewritten
    by the app at runtime (relay names, saved audio settings), so git always saw
    them as locally modified and /update/apply refused to pull. web/trx_config.json
    and web/band_rules.json had the same problem as untracked, unignored files.
    Untrack and gitignore all four, matching the existing client_ip.cfg/
    server_ip.cfg/password.txt convention. /update/apply now also snapshots any
    of these files before resetting them for the pull and restores their live
    content afterwards, so in-progress runtime state survives an update even
    before this migration lan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
    [audio_config.cfg]
2026-08-30 release v1.1.2: show current version on tab open, format changelog
    Update tab now loads the current version immediately via a new
    local-only /update/current endpoint (no GitHub call), rather than
    waiting for Check for Update. The changelog for an available update
    renders as a heading + bullet list per version instead of raw text.
2026-08-30 release v1.1.3: stop blocking updates on harmless untracked files
    Only a locally modified *tracked* file outside the runtime-state
    allowlist now refuses an update; untracked clutter (backups, stray
    files) can't conflict with a fast-forward pull and no longer blocks.
    Also gitignore privatekey/publickey (ser2net/TLS credentials).
    [app.py]
2026-08-30 release v1.1.4: revert v1.1.3, web panel broke on at least one device
    v1.1.3 (untracked-file handling in /update/apply + privatekey/publickey
    gitignore entries) left the web panel with no working tabs/buttons after
    a git pull on a deployed device. Root cause isn't confirmed yet, so
    reverting to the known-working v1.1.2 code rather than debugging blind.
    [app.py]
2026-08-30 release v1.1.5: fix JS-breaking unescaped \n in HTML_TEMPLATE
    HTML_TEMPLATE is a plain (non-raw) Python triple-quoted string, so any
    \n written in the embedded JS to mean "the literal two characters
    backslash-n" was instead parsed by Python as a real newline character
    before the page was ever served. This corrupted a comment and split a
    string literal ('\n') across lines in renderChangelogHtml(), which the
    browser reported as "Uncaught SyntaxError: string literal contains an
    unescaped line break" and broke every tab and button on the page.
    This bug shipped in v1.1.2, not v1.1.3, which is why reverting to
    v1.1.2 in v1.1.4 didn't fix it. All affected \n (and the earlier,
    similarly-fixed \s) a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
    [app.py]
2026-08-30 release v1.1.6: verification bump, no code changes
    Cuts a new tag to test the Update tab's check/apply flow end-to-end
    on a deployed device now that v1.1.5 fixed the broken web panel.
2026-08-30 release v1.1.7: gitignore privatekey/publickey
    Re-adds just the .gitignore entries from the reverted v1.1.3, without
    its untracked-file update-check change, which was the one that broke
    the panel on a deployed device.
2026-08-30 release v1.1.9: read changelog from the fetched tag, not the working tree
    get_changelog_for_new_versions() read CHANGELOG.txt off disk, which only
    reflects whatever commit is currently checked out. A fetched-but-not-yet
    -pulled tag's changelog entries live only in git's object database until
    a pull happens, so Check for Update reported an update was available but
    showed no changelog for it. Now reads CHANGELOG.txt via `git show
    <latest_tag>:CHANGELOG.txt` instead.
2026-09-07 fix some pcb issues
    [nano-server.kicad_pcb, nano-server.kicad_sch, usb_audio.kicad_sch]
2026-09-07 feature: add separate switching for auto relay
2026-09-09 fix online/offline TRX indicator
    [app.py]
2026-09-10 fix gpiod library api
    [combined_ptt_service.py]
2026-09-10 fix gpiod library api final
    [combined_ptt_service.py]
2026-09-10 fix gpiod library api final2
    [combined_ptt_service.py]
2026-09-14 fix ping responce issue
    [app.py, combined_ptt_service.py]
2026-09-14 fix ping responce issue final
    [app.py]
2026-09-14 fix ping cat polling
    [app.py]
2026-09-15 fix an issue on the board
    [nano-server-B_Cu.gbr, nano-server-B_Mask.gbr, nano-server-B_Paste.gbr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]
2026-09-26 fix some issues with cat and ptt
    [app.py, combined_ptt_service.py]
2026-09-26 release v1.2.2: CAT reply filtering, CAT port allowlist, relay lock
    - Server uses its own CI-V controller address (server_addr, default 0xE1);
    radio frames to/from it are decoded but not forwarded to TCP clients/UART1.
    Kenwood: the reply to the server's own IF; poll is kept back.
    - CAT TCP port accepts only 127.0.0.1, the client IP and tcp_allowed_ips.
    - /toggle and /bandrelay/apply are POST-only; SameSite=Lax session cookie;
    /ptt/status and /trx/ports require login.
    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
2026-09-26 Block web QSY during PTT, stop CW on client loss, harden CAT processing
    - /trx/set_freq, /trx/freq_step and /trx/set_band are refused (409) while
    relay switching is locked by PTT (GPIO, CAT or unknown state), so the radio
    can't be moved to another band while keyed into the current antenna.
    freq_step no longer jumps from a made-up 7.1 MHz when the TRX is offline;
    non-numeric freq/step return 400.
    - ptt_server: when the client disappears, a running CW message is stopped,
    the buffer cleared and the key line released (not just PTT). A stopped
    message no longer finishes the current character and re-keys.
    - Band relay rules are validated on the server (numeric from < to, relays
    0-15)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
    [app.py, combined_ptt_service.py]
2026-09-26 release v1.2.3: CAT decoder fixes, Kenwood VFO tracking
    - Icom CI-V: decode transceive reports (00/01), more modes (CW-R, RTTY-R,
    WFM, DV, DD), 6-byte frequencies; handle long/split FE preambles.
    - Kenwood: track the active VFO (IF, FR reports, FR commands from programs);
    FA/FB only update frequency and band relays for the VFO in use; web
    frequency changes go to the active VFO; MD7/MD9 -> CW-R/RTTY-R.
    - Poller freshness is based on when the active frequency was last reported,
    not on any radio reply.
    - Remove the "Extra CAT TCP clients" field from Settings (tcp_allowed_ips is
    still read from trx_config.json).
    - CHANGELOG section for v1.2.3.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
    [app.py]
2026-10-17 Harden PTT packet handling against late and reordered packets
    A keepalive '1' that reached the server after the client's OFF (the
    client could send one while racing its own release) was treated as a
    new press and keyed the transmitter until the 500 ms keepalive timeout.
    A late legacy '1' or an extended packet reordered behind the OFF had
    the same effect.
    - Never re-key on a keepalive after an explicit OFF; after a keepalive
    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
2026-10-18 Close the camera port, update to release tags, validate audio input
    - mjpg-streamer listens on 127.0.0.1 only: port 8081 served the camera
    to anyone who could reach the server, bypassing the panel login. The
    panel's /stream view is unchanged.
    - restart_services_on_server.sh installs changed unit files (only units
    already installed) and reloads systemd, so unit changes reach
    existing installs through Update / Restart Audio Services.
    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
2026-10-18 KiCad: project file saved by newer KiCad (empty net colors/assignments)
2026-10-18 Ignore KiCad automatic backup folders
2026-10-18 release v1.2.4: PTT hardening, closed camera port, release-tag updates, audio input validation
2026-10-22 Open the Kenwood CAT port with RTS/DTR low
    pyserial raises RTS and DTR by default; with them held high an Elecraft K3
    (lines mapped via CONFIG:PTT-KEY) stops answering CAT, so the web UI showed
    no frequency. Icom keeps the default, as some CI-V interfaces are powered
    from these lines.
2026-10-23 Add Elecraft CAT protocol; keep RTS/DTR high for Kenwood
    Elecraft is the Kenwood protocol with the CAT port opened with RTS and
    DTR low: with them high an Elecraft K3 stops answering CAT. Kenwood gets
    pyserial's default (high) back, as f34eb3d made them low for it and a
    TS-590 uses RTS for flow control and stays silent with it low.
